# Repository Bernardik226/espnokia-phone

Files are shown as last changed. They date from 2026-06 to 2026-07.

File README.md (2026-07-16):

<p align="center">
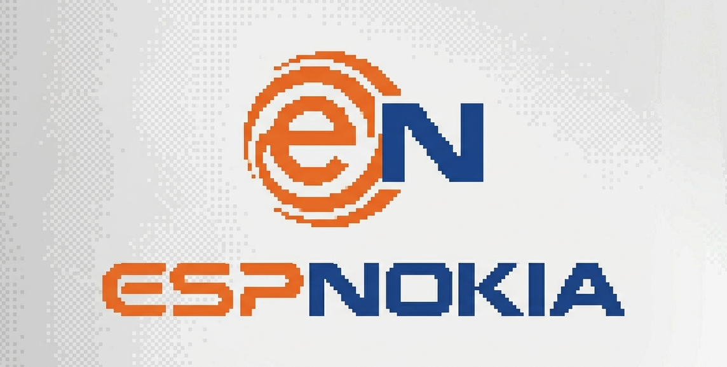
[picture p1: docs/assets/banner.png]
ESPNOKIA
  
</p>

<p align="center">
  
  
  
  
</p>

<p align="center">
  
  
  
  
</p>

<p align="center">
  🇬🇧 English&nbsp;&nbsp;·&nbsp;&nbsp;<a href="README.pt-br.md">🇧🇷 Português</a>&nbsp;&nbsp;·&nbsp;&nbsp;<a href="docs/INSTALL.md">🔧 Build yours</a>&nbsp;&nbsp;·&nbsp;&nbsp;<a href="docs/ARQUITETURA.md">🏛️ Architecture</a>&nbsp;&nbsp;·&nbsp;&nbsp;<a href="docs/MAKE_AN_APP.md">🧩 Make an app</a>
</p>

---

<p align="center"><b>A Nokia 3310 that talks to Claude — firmware, printed case, backend and PWA, all built by me.</b></p>

I built this handheld from scratch to fold everything I wanted to show into one project: **embedded firmware** on an ESP32, a **case I designed and printed**, an **AI-powered FastAPI backend** and a **configuration PWA**. It's my end-to-end portfolio — from the pixel on the 84×48 screen to the container on deploy. Year-2000 looks, 2026 features.

<p align="center">
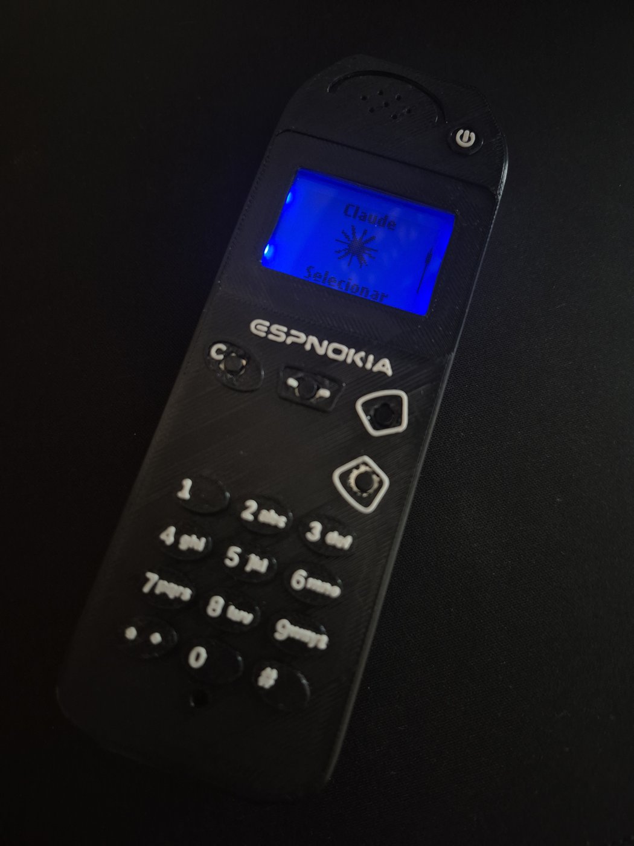
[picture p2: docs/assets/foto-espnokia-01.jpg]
assembled espnokia — the printed, powered device showing the Claude app on screen
  
</p>

<p align="center">
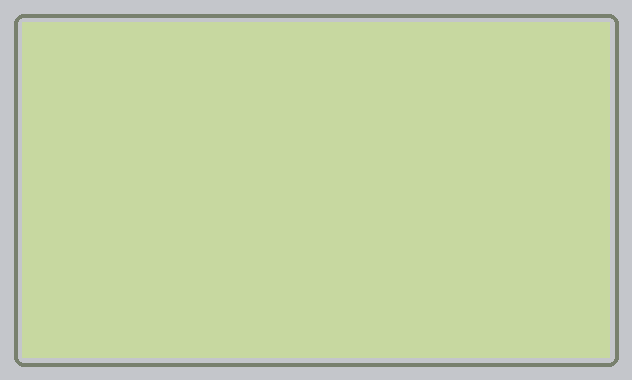
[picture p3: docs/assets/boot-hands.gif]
the recreated Nokia boot animation: two pixel hands meet and the logo lights up
  
</p>

---

## ✨ What it does

- 🐾 **Claw'd — talk to Claude.** Hold the button, speak, release: the mic captures, the server transcribes, **Claude answers**, and a pixel-art critter reads the reply on the little screen. Every exchange becomes a **log**, and a rolling **memory** lets the pet remember you across reboots.
- 🏆 **World Cup 2026, live.** Upcoming matches, Brazil's games, a live panel and group tables. Flag a match and the device **rings when it kicks off**; the score updates on its own and **"GOAL!" flashes on screen** the instant it changes.
- ⚽ **Club leagues.** Champions League, Libertadores and friends, with a standings table that **adapts to the competition** (numbered league table / navigable groups).
- ⏰ **3310-style daily life.** A clock with an **alarm that survives reboots** and a timer, ambient temperature from the DS3231, and **9 original Nokia ringtones** in RTTTL.
- 🐍 **Snake II.** The classic, with its own engine tested on the PC.
- 📶 **WiFi with no recompile.** The device becomes an access point with a captive portal and a freshly-drawn password — switch network and server URL with no cable and no reflash.
- 🌍 **9 languages** across the whole system; **99 native tests** of pure logic + **157 on the server**.

<table align="center">
<tr>
<td align="center" width="50%">
  push-to-talk with Claw'd: listening, thinking, answering<br>
  <b>🐾 Claw'd</b> — hold, speak, Claude answers
</td>
<td align="center" width="50%">
  navigating the World Cup app on the device<br>
  <b>🏆 WC 26</b> — live on an 84×48 screen
</td>
</tr>
</table>

<p align="center">
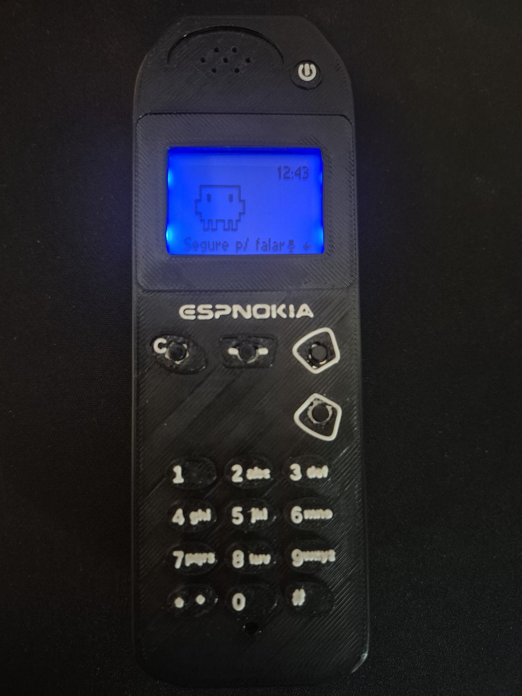
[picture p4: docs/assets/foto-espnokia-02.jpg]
espnokia in use — the clock and the Claw'd pet on the monochrome screen
  
</p>

**Configuration via the PWA.** An installable web panel (the "EspNokia Dash") **configures the device**: pair/discover by QR, see the **online status**, pick **Claude's personality**, the transcription engine, and drop in the **AI key** — with no config screen on the Nokia itself.

---

## 🔍 How it works

It's **three pieces** that talk over an authenticated API (`X-Device-Key`). The ESP32 is a plain chip, **no PSRAM** and with little RAM/flash — so it stores no history and transcribes nothing: it keeps only fixed buffers, a state machine, and **paginates** what it needs. All the durable state (the pet's memory, transcription, Claude calls) lives on the **server**, which **summarizes** old conversations so the context never grows without bound.

> **The core idea:** a *thin client* on the ESP32 (fixed, byte-capped buffers) + a *fat server* that holds and summarizes the history. That's how the firmware fits in **~⅓ of the flash and ¼ of the RAM** (flash 36.1% / RAM 25.6%).

```mermaid
flowchart LR
    D["📟 Firmware (ESP32)<br/>thin client"]
    S["🐍 Server (FastAPI · Docker)<br/>fat server"]
    P["📱 PWA<br/>configuration"]
    D -- "POST /claude/voz · PCM16<br/>GET /copa /futebol /claude/registro" --> S
    S -- "lean JSON · paginated text" --> D
    P -- "/admin/* · X-Device-Key" --> S
```

Architecture and technical decisions → **[docs/ARQUITETURA.md](docs/ARQUITETURA.md)** (in Portuguese for now)

---

## 🔌 Hardware

| | Component | Role |
|---|---|---|
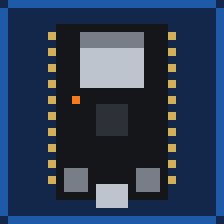
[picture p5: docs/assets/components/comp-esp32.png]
ESP32
|  | **ESP32 WROOM-32** DevKit, 30 pins | Brain: WiFi, 2 cores, the whole NokiaOS |
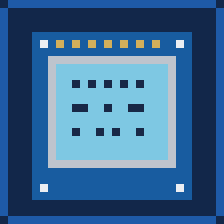
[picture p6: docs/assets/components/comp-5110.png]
Nokia 5110
|  | **Nokia 5110 display** (PCD8544) | 84×48 monochrome — the real Nokia panel, over SPI |
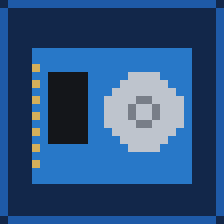
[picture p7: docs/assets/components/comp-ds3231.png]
DS3231
|  | **DS3231 RTC** | Battery-backed time + on-board thermometer, over I2C |
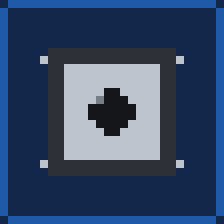
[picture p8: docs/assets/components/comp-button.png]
buttons
|  | **4 tactile buttons** | UP · DOWN · OK · C — full 3310-style navigation |
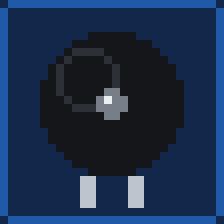
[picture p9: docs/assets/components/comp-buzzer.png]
buzzer
|  | **Passive buzzer** | RTTTL ringtones, beeps and the goal alert (volume via PWM) |
| 🎤 | **I2S mic INMP441** | Captures your voice for Claw'd |
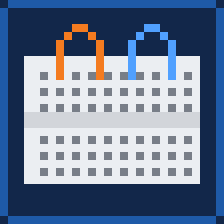
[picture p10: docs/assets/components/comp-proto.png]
breadboard
|  | **Breadboard + wires** | No-PCB, hand-wired build — full pinout in [`docs/INSTALL.md`](docs/INSTALL.md) |

> **No PCB, on purpose.** I chose to skip a dedicated board for simplicity and the low component count — I wired everything **by hand** (breadboard + soldering straight to the modules). The real challenge was soldering and securing all the wires; but closed inside the case, it all stays **discreet**. A PCB mainboard is planned for v2.

<table align="center">
<tr>
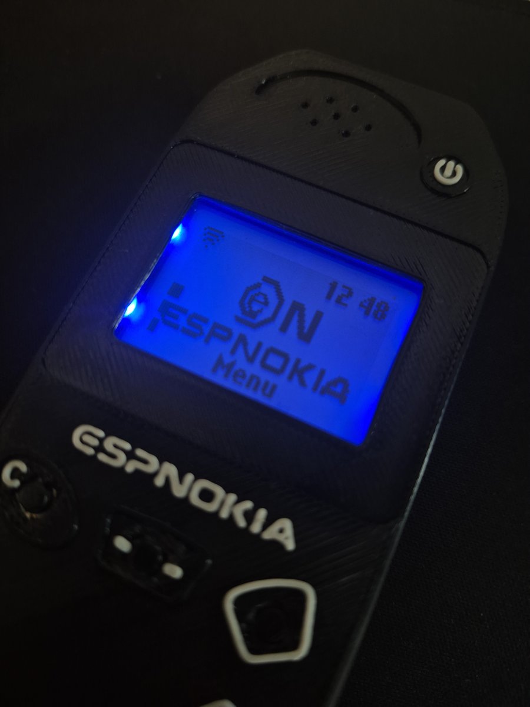
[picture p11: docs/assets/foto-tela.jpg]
close-up of the lit screen showing the eN emblem and the menu
<td align="center" width="33%"><br><sub><b>Lit screen</b> · eN + menu</sub></td>
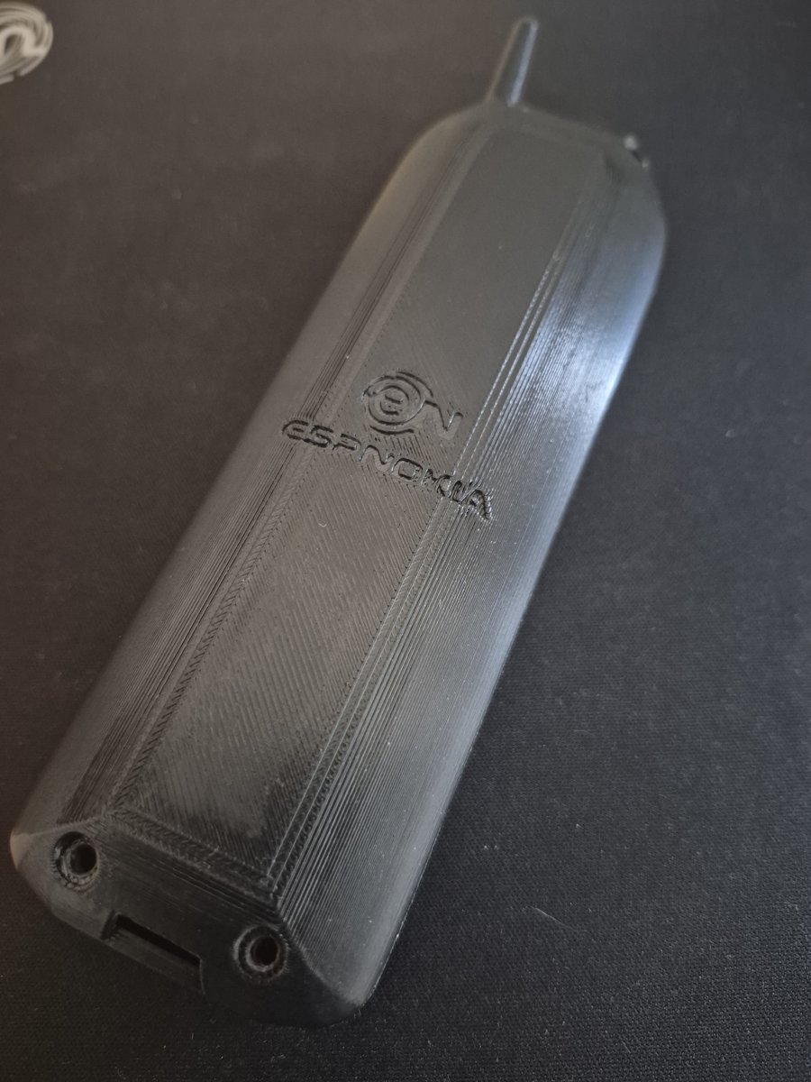
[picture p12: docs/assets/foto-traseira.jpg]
back cover with the eN emblem engraved into the dome
<td align="center" width="33%"><br><sub><b>Back</b> · logo engraved on the dome</sub></td>
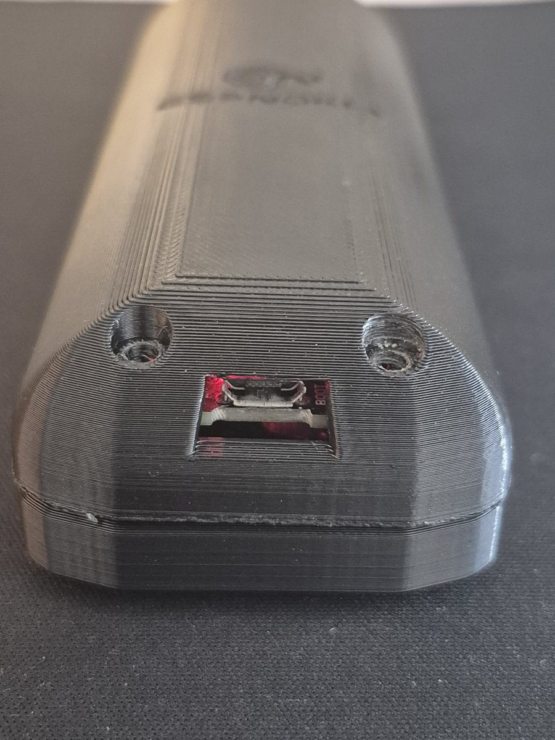
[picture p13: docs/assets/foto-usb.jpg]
USB port on the base — the ESP32's own micro-USB
<td align="center" width="33%"><br><sub><b>Base USB</b> · charge + flash via the ESP32</sub></td>
</tr>
</table>

**From file to part.** I designed the case in OpenSCAD/FreeCAD and exported the front as **multi-color** (black body + white silkscreen, two objects in one `.3mf`). The two slice-ready files (front + back) live in [`hardware/Case/print/`](hardware/Case/print) — just open and print.

<table align="center">
<tr>
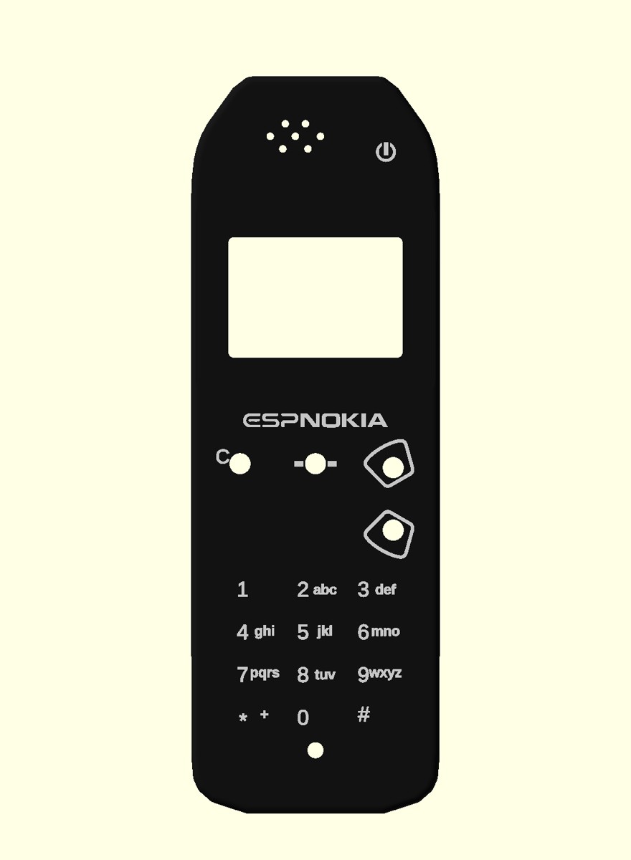
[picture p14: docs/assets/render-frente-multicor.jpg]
multi-color front render: black body and white silkscreen
<td align="center" width="50%"><br><sub><b>Multi-color front</b> · the final file (2 colors)</sub></td>
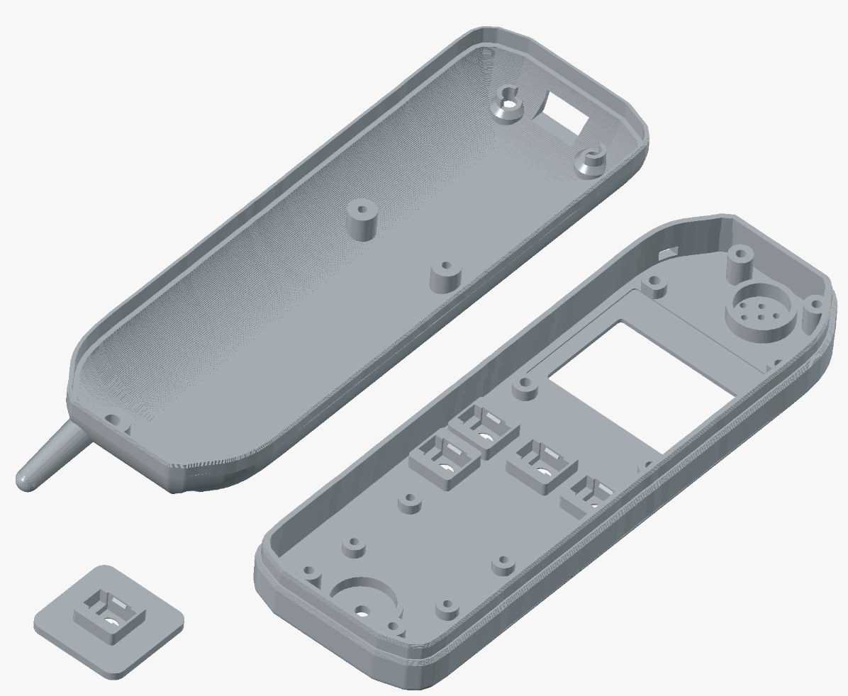
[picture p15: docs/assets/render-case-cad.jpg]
case opened in FreeCAD: front, back cover and a fit part
<td align="center" width="50%"><br><sub><b>In FreeCAD</b> · front + back + fits</sub></td>
</tr>
</table>

---

## 🚀 Run / build

```bash
# Firmware (PlatformIO) — from firmware/
cd firmware
pio run  -e esp32dev     # builds and flashes the ESP32
pio test -e native       # 99 pure-logic tests, run on the PC

# Server (FastAPI) — from server/
cd server
docker build -t espnokia .
docker run -p 8000:8000 --env-file .env espnokia   # ANTHROPIC_API_KEY is the only required one
```

**Deploy:** the plain `Dockerfile` runs on any container host — it's published on **Railway**. Then just open *Settings → Connections* on the device and point it at the server URL (no reflash). Full build guide in **[docs/INSTALL.md](docs/INSTALL.md)**.

---

## 🙏 Credits & attributions

This project stands on open work, with thanks:

- **Data** — [openfootball](https://github.com/openfootball/world-cup) (public-domain World Cup dataset) · **ESPN** (live scores and leagues via public endpoints; data © ESPN / The Walt Disney Company).
- **AI & voice** — [Anthropic Claude](https://www.anthropic.com/) (Claw'd's brain) · [faster-whisper](https://github.com/SYSTRAN/faster-whisper) (local STT) · [Groq](https://groq.com/) (cloud STT, optional).
- **Art & fonts** — [nokia-3310-fonts](https://git.janouch.name/p/nokia-3310-fonts) by **Premysl Janouch** · the Nokia 1100 boot and factory ringtones reproduced as an homage.
- **Libraries** — [U8g2](https://github.com/olikraus/u8g2) · [ArduinoJson](https://arduinojson.org/) · [QRCode](https://github.com/ricmoo/QRCode) · [FastAPI](https://fastapi.tiangolo.com/) · [Uvicorn](https://www.uvicorn.org/) · [httpx](https://www.python-httpx.org/) · [Anthropic SDK](https://github.com/anthropics/anthropic-sdk-python).

---

## ⚖️ Trademarks & authorship

**Nokia** and the Nokia phone designs are trademarks of **Nokia Corporation**. **Claude** and **Anthropic** are trademarks of **Anthropic, PBC**. The **FIFA World Cup** name and emblem are trademarks of **FIFA**. **Groq**, **ESPN** and other names belong to their respective owners. This is an independent, **non-commercial, fan & educational** project — a tribute — and is **not affiliated with, endorsed by, or sponsored by** any of them.

Original code, firmware, pixel art and assets © 2026 **Bernardo Melo**. Third-party components keep their own licenses.

<p align="center">
  Want one on your desk? → <a href="docs/INSTALL.md"><b>🔧 Build guide</b></a>
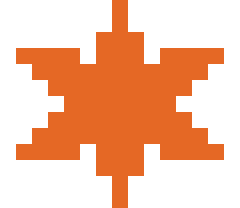
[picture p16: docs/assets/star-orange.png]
orange star
  &nbsp;·&nbsp;  built by <b>Bernardo Melo</b>
</p>

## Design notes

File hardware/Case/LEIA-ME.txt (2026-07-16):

=========================================================
espnokia — case (Nokia 5110) — imprimir & montar
=========================================================

2 pecas pra imprimir (print/) + 2 STL de conferencia de encaixe (sim/).

IMPRIMIR
--------
print/ (ja caem na orientacao certa no slicer — NAO virar):
- frente-multicor.3mf .. frente: corpo preto + serigrafia branca (logo,
                         teclado, simbolos). Sao 2 objetos/cores no mesmo
                         arquivo -> numa impressora de 1 bico, faca troca de
                         filamento (pausa na camada onde a serigrafia comeca).
                         Botoes de navegacao em relevo, switch direto, torres
                         do RTC atras do teclado.
- case-capa.3mf ........ tampa traseira; furo do USB com funil, luvas
                         meia-lua p/ os botoes do ESP, sem RTC.

Orientacao: a frente sai com o TECLADO PRA CIMA; a capa com o DOMO PRA CIMA
(boca pra baixo). Nao virar nenhuma das duas.

Perfil sugerido (ABS resistente):
- camada 0,16mm (primeira camada 0,20)
- 4 paredes; topo/fundo 5/4; infill 40% GIROIDE (nao use grid)
- suporte NORMAL (grade), "apenas na mesa", com interface — NAO use arvore
- brim 8-10mm
- ABS: bico 245-255 / mesa ~100, camara fechada, fan baixa
- no preview: nada de suporte sobre a face do teclado

sim/ (NAO imprimir — so p/ conferir encaixe no FreeCAD):
- sim-tela-modulo.stl .. modulo 5110 nas medidas reais
- sim-esp32-capa.stl ... ESP32 DevKit no lugar de montagem (confere USB,
                         botoes e pinos)

MONTAR
------
1) Switches tatil 6x6 por TRAS da frente, ate estalarem nos bercos. A ponta
   do atuador sai pelo furo -> o dedo clica direto nela.
2) ESP32 na TAMPA, de cabeca pra baixo: componentes/USB contra o fundo, pinos
   pra cima. Parafuse so os 2 furos de cima; os 2 de baixo recebem os
   parafusos da case ao fechar.
3) RTC DS3231 na FRENTE, deitado atras do teclado (socket da pilha pra cima).
4) Bateria (com modulo de carga) colada no fundo da tampa.
5) Feche: 4 parafusos pelas costas (os 2 de baixo atravessam os furos do ESP).

LIGACAO (carga + flash pela porta USB da base = micro-USB do proprio ESP32)
--------
  VIN/5V do ESP --> IN+ do TP4056
  TP4056 B+/B-  --> bateria LiPo
  TP4056 OUT+   --> diodo Schottky (SS14/1N5817) --> VIN do ESP
  TP4056 OUT-   --> GND comum
  Com USB: os 5V carregam a bateria (o Schottky bloqueia o retorno).
  Sem USB: bateria -> Schottky -> VIN -> regulador 3,3V da placa.
  (Carregue de preferencia com o aparelho desligado.)

LIGA/DESLIGA
------------
Mini chave deslizante na lateral direita (o relevo do power na frente e
decorativo). Ligacao: VOUT+ da bateria (apos o diodo) -> chave -> VIN.

PARAFUSOS
---------
- 2x M2,5 ~20mm .. fecham a case por baixo (atravessam o furo do ESP)
- 2x M2,5 6-8mm . ESP32 nos standoffs de cima
- 4x M2,5 4-5mm . RTC nas torres da frente
- 2x M2,5 ~16mm . case por cima
- 4x M3 curto ... tela nos bosses da frente

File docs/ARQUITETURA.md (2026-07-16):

# Arquitetura & decisões técnicas — espnokia-phone

Este documento explica **como o projeto está montado por dentro** e as decisões que tomei pra fazer um handheld estilo Nokia 3310 rodar um assistente de voz com o Claude — mantendo histórico de conversa — num **ESP32 comum, sem PSRAM**. Se você quer a visão de vitrine (o que o aparelho faz), volte pro [README](../README.pt-br.md); aqui é a parte de engenharia.

O fio condutor é um só: **cliente magro no firmware, server gordo no backend.** O chip guarda o mínimo e pagina o resto; o server segura o estado durável e resume o que fica grande demais.

---

## 1. As 3 partes + contrato de API

| Parte | Stack | Papel |
|---|---|---|
| **Firmware** | ESP32 (C++17 / Arduino / U8g2, PlatformIO) | Cliente magro: UI, captura de voz, paginação sob demanda |
| **Server** | FastAPI / Uvicorn (Docker) | Server gordo: transcrição, chamadas ao Claude, memória durável, mastiga fontes de dados |
| **PWA** | HTML/JS de página única (sem framework) | Configuração do aparelho: pareamento, status, chaves, persona |

O firmware **nunca** toca uma fonte externa direto — ele só fala com o *meu* server, que é a membrana entre um buffer de poucos KB e a internet aberta. Toda rota (menos o essencial de saúde/PWA) exige o header **`X-Device-Key`**.

### Autenticação — `X-Device-Key` (`server/app/auth.py`)

A dependency `make_auth` valida o header em 3 modos, pela env `DEVICE_KEYS`:

- **`""`** → auth desligada (dev local).
- **`"*"`** → modo **capability**: aceita qualquer chave com `len ≥ 16`. A própria chave forte (32 hex = 128 bits, gerada no device) *é* a credencial; não há lista de usuários no servidor, e os dados ficam **isolados por hash da chave**. É o modo do pareamento por QR — um aparelho se registra sem cadastro central.
- **`"a,b"`** → allowlist clássica de chaves.

O dashboard e o device usam **a mesma auth**: o painel web é literalmente o mesmo "device" logado com a chave.

### Rotas

**Device-facing** (chamadas pelo firmware ESP32):

| Método | Rota | O que faz |
|---|---|---|
| `GET` | `/health` | Ping de keep-alive do socket — **sem auth**. |
| `GET` | `/copa/proximos?n=8` · `/copa/brasil` · `/copa/live` · `/copa/grupos` | Placares/tabela da Copa 2026 (payload compactado, chaves de 1 letra pra caber no buffer do ESP32). |
| `GET` | `/futebol/ligas` · `/futebol/jogos?liga=` · `/futebol/live?liga=` · `/futebol/tabela?liga=` | Futebol de clubes (ligas, jogos, ao vivo, classificação). |
| `POST` | `/claude/voz?lang=pt&t=` | **Rota central da voz.** Corpo = PCM16 cru; dispara STT → Claude → resposta; se o histórico encheu, agenda o resumo em background. |
| `GET` | `/claude/registro?pag=0` | Histórico paginado (6 pares por página). |
| `GET` | `/claude/memoria` | Memória resumida (markdown) + contador de resumos. |
| `POST` | `/claude/memoria/limpar` | Apaga registro + memória ("esquecer tudo"). |

**PWA / admin-facing** (dashboard):

| Método | Rota | O que faz |
|---|---|---|
| `GET` | `/admin/status` | Versão, motor de STT, modelo, web search, se tem API key, total de conversas, nº de resumos, timestamp da memória. |
| `GET` | `/admin/config` | Config atual: `persona_id` + catálogo de personas, modelo, STT, limite de resposta, web search, e **flags booleanas** `tem_anthropic_key` / `tem_stt_key` — **nunca a chave crua**. |
| `POST` | `/admin/config` | Grava campos parciais; a chave de API só é sobrescrita se vier não-vazia (evita apagar sem querer); `persona_id` só é aceito se existir no catálogo. |
| `GET` | `/manifest.json` · `/sw.js` · `/` | Shell do PWA (sem auth). |

---

## 2. A restrição-chave e como resolvi

**O problema:** rodar o Claude *com memória de conversa* num ESP32 WROOM-32 — sem PSRAM, com RAM e flash apertadas (por isso `board=esp32dev` + partição `huge_app.csv`: abri mão de OTA/SPIFFS pra ter espaço de código). Um histórico de chat cresce sem limite; um buffer de resposta multibyte estoura fácil; e transcrição de áudio no chip é impensável.

**A solução:** dividir responsabilidades. O device fica *magro*; o server fica *gordo*.

### Lado device — só o que cabe em RAM fixa

- **Buffers fixos, dimensionados em bytes** (`firmware/lib/claudemodel/claudemodel.h`). Nada de alocação dinâmica:
  ```cpp
  struct RegPar {
    char q[164];   // MAX_Q_BYTES do server (160) + nul
    char r[284];   // MAX_R_BYTES do server (280) + nul
    char d[6];     // "dd/mm"
    char h[6];     // "hh:mm"
  };
  ```
  Os tamanhos **164 / 284 espelham literalmente** os tetos do server (`MAX_Q_BYTES` / `MAX_R_BYTES` + 1): o firmware não decide o teto sozinho, ele reflete o do servidor. `registro_parse(RegPar* itens, uint8_t max)` recebe do *caller* quantos pares cabem — quem manda na RAM é o app, não a lib.
- **Máquina de estados push-to-talk** (testável no PC, sem Arduino):
  ```
  E_PET → (OK aperta) → E_OUVINDO → (OK solta) → E_PENSANDO → (resposta|falha) → E_FALANDO → (volta) → E_PET
  ```
  Com timeouts de segurança: `kOuvindoMaxMs = 15 s` corta a gravação; `kFalandoMaxMs = 60 s` volta sozinho ao pet. O `E_PENSANDO` **não** tem timeout próprio de propósito — quem corta é o timeout do cliente HTTP (`kRespTimeoutMs = 20 s`).
- **Paginação, não replicação.** O histórico completo **não existe no device**: `GET /claude/registro?pag=N` devolve só uma página (6 pares), e o firmware guarda no máximo o array da página atual. Entre reboots o device persiste só **a chave e a URL do server** (em NVS) — nenhuma conversa fica na flash.
- **Consciência de heap explícita.** O upload de voz vai por **HTTP chunked**: o PCM16 é escrito direto no socket TLS conforme a captura, chunk a chunk, sem montar o corpo inteiro em RAM. O socket TLS é mantido "quente" e reusado entre chamadas, e `ESP.getFreeHeap()` é logado em cada tentativa de rede. (O TLS usa `setInsecure()` de propósito — "o segredo do device é a chave, não o canal"; o ESP32 não carrega um bundle de CAs atualizado.)

### Lado server — o estado durável e o resumo (`server/app/memoria.py`)

Esse arquivo é o coração da solução. Por device, guardo em disco (`DATA_DIR/claw/<id8>/`, onde `id8 = sha256(chave)[:8]` — a chave secreta nunca vira nome de pasta):

- **`registro.json`** — `{"pares": [...], "resumidos": int}`; cada par é `{ts, q, r}`. Escrita **atômica** (`tmp` + `os.replace`).
- **`memoria.md`** — texto livre em markdown, um resumo cumulativo em 1ª pessoa que o **próprio Claude** escreve. Legível de propósito.

Os limites que governam tudo:

```python
MAX_PARES = 30           # atingiu -> dispara resumo
VARRE     = 20           # pares mais antigos fundidos na memória e removidos
TETO      = 40           # rede de segurança: acima disso descarta o mais antigo
PARES_POR_PAG = 6        # paginação do GET /claude/registro
MAX_Q_BYTES = 160        # pergunta truncada (buffer do ESP32)
MAX_R_BYTES = 280        # resposta truncada (buffer do ESP32)
MAX_MEMORIA_CHARS = 1500 # teto do memoria.md
```

**O mecanismo de resumo (contexto limitado):**

1. Depois de cada `/claude/voz` bem-sucedido, `precisa_resumo()` checa se `len(pares) ≥ 30`. Se sim, agenda `resumir()` num **`BackgroundTasks`** — não bloqueia a resposta ao aparelho, e se falhar só loga.
2. `resumir()` pega os **20 pares mais antigos** + o `memoria.md` atual e pede pro Claude **reescrever a memória inteira** em 1ª pessoa, no idioma do usuário, em até **1500 caracteres**. Ou seja: cada resumo **funde** o velho com o novo e é resumido de novo — não é um log incremental, o tamanho fica sempre controlado.
3. O resultado é truncado e salvo atomicamente; os 20 pares resumidos são removidos do `registro.json` — mas o registro é **recarregado do disco antes de filtrar**, pra não perder um par que chegou enquanto o resumo (em background) pensava.
4. **Rede de segurança:** se o resumo nunca rodar (sem API key, falha contínua), `grava_par` corta o array pros últimos **40 pares** a cada gravação — um cap duro que impede o `registro.json` de crescer sem limite, ao custo de descartar silenciosamente os mais antigos ainda não resumidos.

O efeito é o que importa: **o contexto que mando pro Claude a cada fala nunca é o histórico completo.** É `memoria.md` (≤ 1500 chars) + só os **últimos 6 pares** crus + a fala atual. O histórico completo em disco existe só pra exibição paginada no aparelho/dashboard — jamais é reenviado inteiro ao modelo.

### `corta_utf8` — a ponte de segurança de bytes entre Python e C

O truncamento é feito **em bytes, não em caracteres Python**, porque o firmware aloca `char q[164]` / `char r[284]` fixos. Cortar por caractere estouraria o buffer C num texto multibyte (acentos, emoji):

```python
def corta_utf8(s: str, max_bytes: int) -> str:
    b = s.encode("utf-8")
    if len(b) <= max_bytes:
        return s
    corte = b[:max_bytes - 3]          # reserva 3 bytes pro "…"
    while corte:
        try:
            return corte.decode("utf-8") + "…"
        except UnicodeDecodeError:
            corte = corte[:-1]         # descarta byte de continuação partido
    return "…"
```

Uso o mesmo `corta_utf8` no corte ao vivo da resposta e na paginação do histórico — assim a fala "ao vivo" e o registro mostram **exatamente o mesmo texto**, e o firmware nunca recebe mais bytes do que o buffer aguenta.

### Footprint

Com o NokiaOS inteiro, os apps, WiFi/TLS e o pipeline de voz, o firmware ocupa **flash 36.1% / RAM 25.6%** — cerca de um terço da flash e um quarto da RAM. Sobra folga de propósito: cada nova tela é uma struct de callbacks, não uma reforma de memória.

<p align="center">
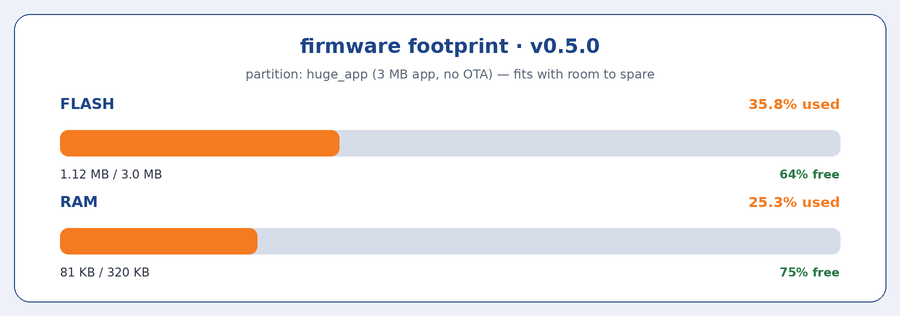
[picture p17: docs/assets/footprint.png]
footprint do firmware na partição huge_app: flash ~36% usada, RAM ~26% usada
  
</p>

---

## 3. Transcrição (STT)

A transcrição é **plugável** via `cfg["stt"]` (default `"local"`), trocável pelo dashboard sem reflash:

- **`local`** (padrão) — **faster-whisper `small`, quantização int8, na CPU**. É **lazy-load**: o modelo só carrega na primeira fala, pra não atrasar o boot; com `STT_PRELOAD=1` eu aqueço no boot quando quero latência baixa já na primeira interação. Roda sem depender de rede nem de chave externa.
- **`groq`** (opcional) — `POST` pra `api.groq.com/.../audio/transcriptions`, modelo **`whisper-large-v3-turbo`** (mais rápido/melhor, mas precisa de chave e rede).

### O fluxo de uma fala (`server/app/claude_voz.py`)

```
PCM16 16 kHz cru no corpo (MAX_CORPO = 500 KB ≈ 15,6 s)
   → transcrever()                       # STT local ou Groq
   → _chat_anthropic()                   # Claude Messages API
        · modelo vindo do cfg (classe Haiku, por custo/latência)
        · max_tokens = 300               # cabe na tela e segura o custo
        · web search server-side, max_uses = 1   # ≤ 1 busca por fala
   → JSON  { resposta, humor, ... }       # texto já cortado no orçamento de bytes
```

O ponto que amarra tudo à seção anterior: **a memória resumida (`memoria.md`) entra no `system` prompt** do Claude a cada fala. É isso que dá continuidade — o pet lembra de você **mesmo depois de reiniciar o server**, sem nunca carregar o histórico cru inteiro no contexto. A resposta já sai truncada pelo mesmo teto de bytes que o ESP32 pagina, então o que o Claude gera, o que a tela mostra e o que o histórico guarda são o mesmo texto.

---

## 4. O que a PWA configura

O PWA (`server/app/static/dashboard.html`) é um SPA de página única, sem framework, com i18n embutido (9 idiomas, troca em runtime persistida em `localStorage`). Ele não é firmware — é o **painel de configuração do aparelho**, instalável no celular. Descrevo aqui por **função** (a aparência será reformulada numa próxima rodada):

- **Pareamento por QR / descoberta.** O aparelho sorteia a própria chave no primeiro boot (RNG de hardware → NVS) e mostra um QR com o link `.../#k=<chave>`. Ao abrir, o JS lê a chave do fragmento, entra **já logado** e limpa a URL (`history.replaceState`) — a chave não fica visível na barra de endereço.
- **Login por chave.** Campo de chave testado contra `GET /admin/status`; 401 mostra "chave recusada", chave válida persiste em `localStorage`.
- **Status online.** Espelho read-only de `/admin/status`: versão, nº de conversas, nº de resumos, motor de STT, modelo, se a web search está ligada, se a chave Anthropic está configurada, quando a memória foi atualizada.
- **Configuração do Claw'd.** Escolher a **personalidade/persona** (catálogo em `config.PERSONAS`, ex.: Fofo, Sarcástico, Poeta, Sábio…), o **motor de STT** (local/Groq), o **modelo** do Claude, o **limite de resposta**, ligar/desligar **busca web**, e colar a **chave de API Anthropic** (campo senha — vazio = manter a atual). Grava via `POST /admin/config`.
- **Memória & conversas.** Ler o `memoria.md` cru, apagar tudo ("esquecer tudo" → `/claude/memoria/limpar`), e navegar as conversas paginadas (`/claude/registro`).

Não há gestão multi-device nem contas: **1 chave = 1 device = 1 sessão de configuração**.

---

## 5. Infra & organização

- **Dockerizado.** `server/Dockerfile` parte de `python:3.12-slim`, copia `requirements.txt` primeiro (cache de layer), expõe a 8000 e roda `uvicorn app.main:app`. Imagem simples, deploy único.
- **Pastas isoladas**, cada uma com seu próprio ciclo de build/test — sem tooling de monorepo compartilhado:
  ```
  firmware/   NokiaOS em C++/Arduino (PlatformIO: esp32dev + native)
    lib/      lógica pura testável: shell, btnlogic, rtttl, i18n, copamodel, claudemodel, snakegame...
    src/      drivers, apps, som, rede (wifi/http/ntp/provisionamento), conn
  server/     companion FastAPI: /copa /futebol /claude /admin + o dashboard PWA
  hardware/   case 3D / STL / configs de impressão
  docs/       instalação, arquitetura, assets
  tools/      utilitários de pixel art (grade → XBM)
  ```
- **Testes nativos.** `firmware/test/` roda no PC via PlatformIO Unity (ambiente `[env:native]`, sem placa): **99 casos** cobrindo shell, botões, RTTTL, formatação de hora, parse da Copa/futebol, o modelo do Claw'd, i18n e o Snake. `server/tests/` são **157 testes pytest** (fontes mockadas, auth, cache, personas, memória, endpoints). A separação `drivers/` (hardware) · `lib/` (lógica pura portável) · `apps/` (UI) é justamente o que permite testar no PC o que roda no ESP32.
- **Deploy — Railway.** O contrato de deploy é o `Dockerfile` plano (sem `railway.json`/`Procfile` versionados), compatível com Railway ou qualquer host de container. Envs relevantes: `DEVICE_KEYS` (allowlist / vazio / `*` capability), `ANTHROPIC_API_KEY` e `GROQ_API_KEY` (seed inicial, depois editáveis só pelo dashboard), `DATA_DIR`, `STT_BACKEND`, `STT_PRELOAD`, `LIVE_SOURCE_URL` (fonte reserva de placar ao vivo).

---

*Voltar pra vitrine → [README](../README.pt-br.md) · Montar o seu → [docs/INSTALL.pt-br.md](INSTALL.pt-br.md)*

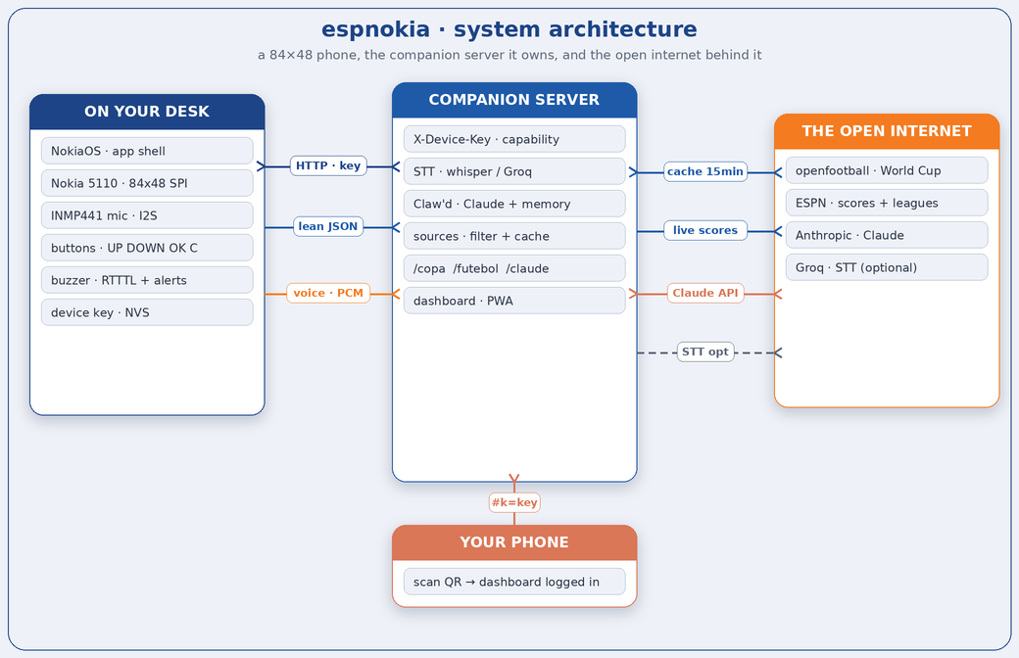
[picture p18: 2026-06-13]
docs/assets/architecture.png

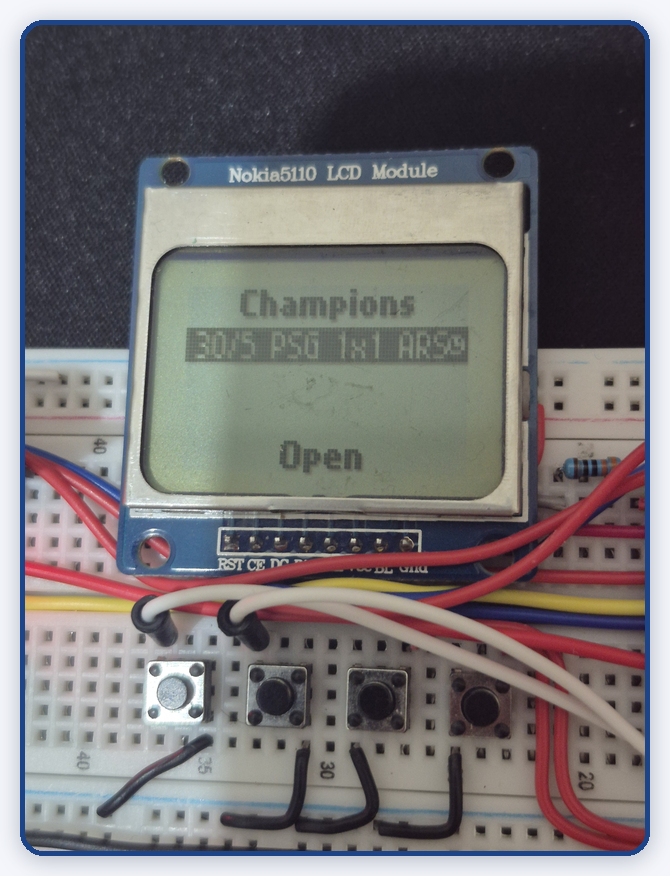
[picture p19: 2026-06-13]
docs/assets/photos/football-champions.png

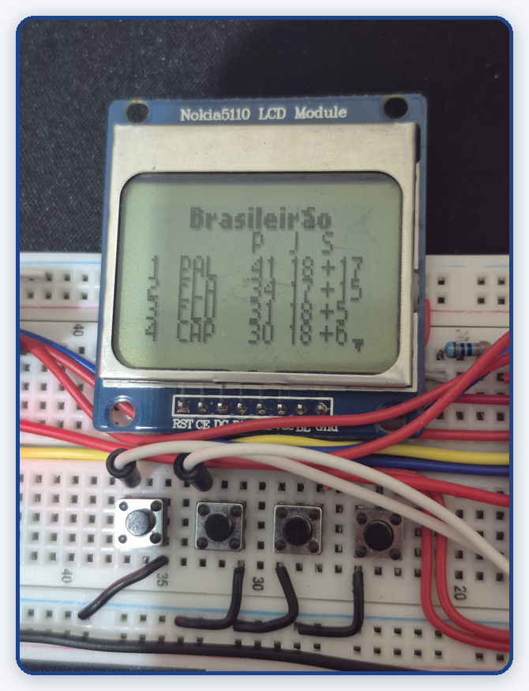
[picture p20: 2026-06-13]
docs/assets/photos/football-table.png

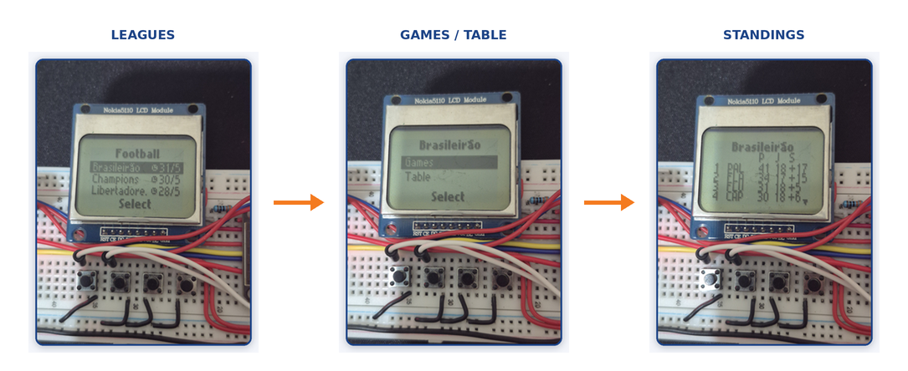
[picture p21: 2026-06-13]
docs/assets/flow-football.png

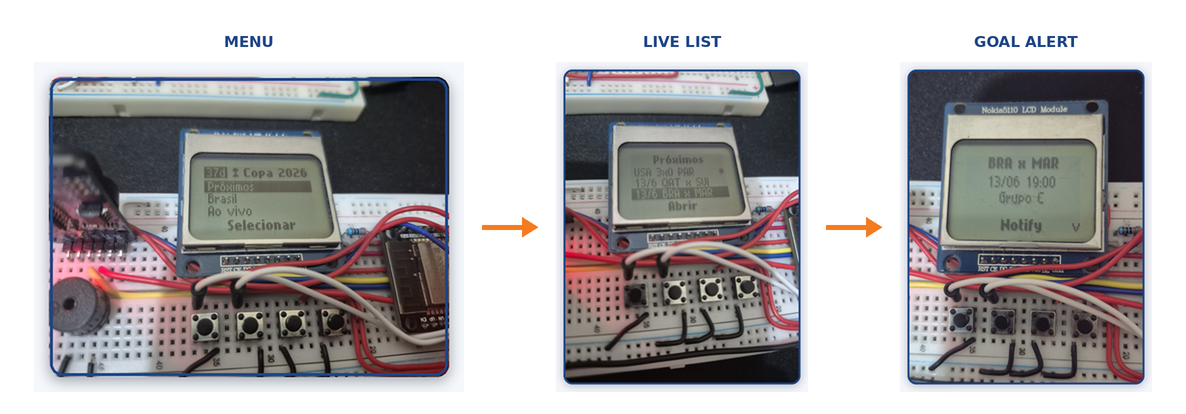
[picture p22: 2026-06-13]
docs/assets/flow-copa.png

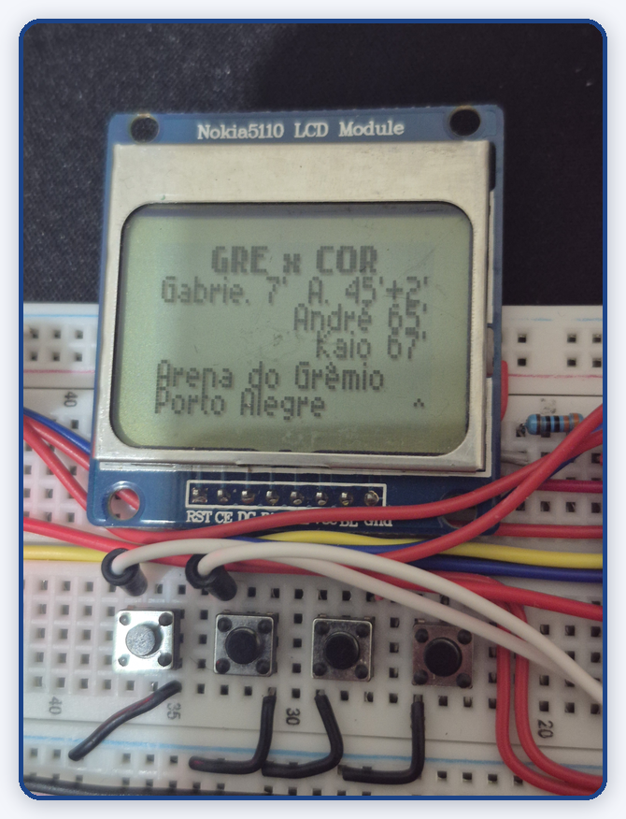
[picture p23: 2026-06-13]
docs/assets/photos/football-game.png

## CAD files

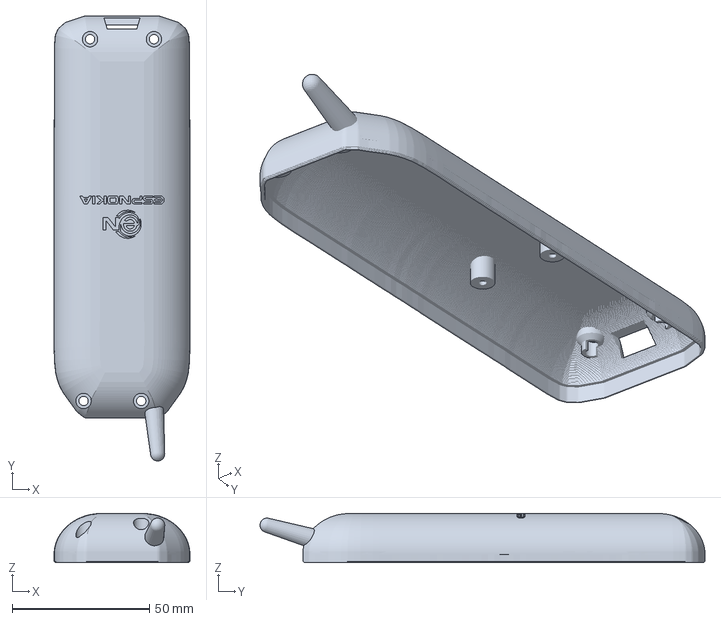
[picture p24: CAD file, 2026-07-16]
hardware/Case/print/case-capa.3mf
49.5 x 162.2 x 18.0 mm

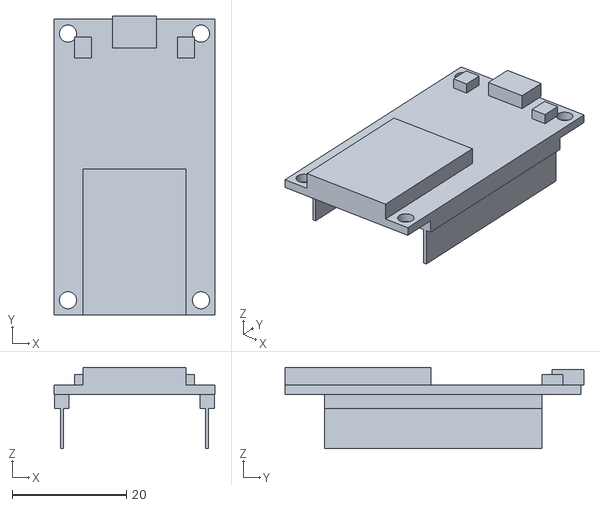
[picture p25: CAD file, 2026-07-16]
hardware/Case/sim/sim-esp32-capa.stl
28.2 x 52.3 x 14.2

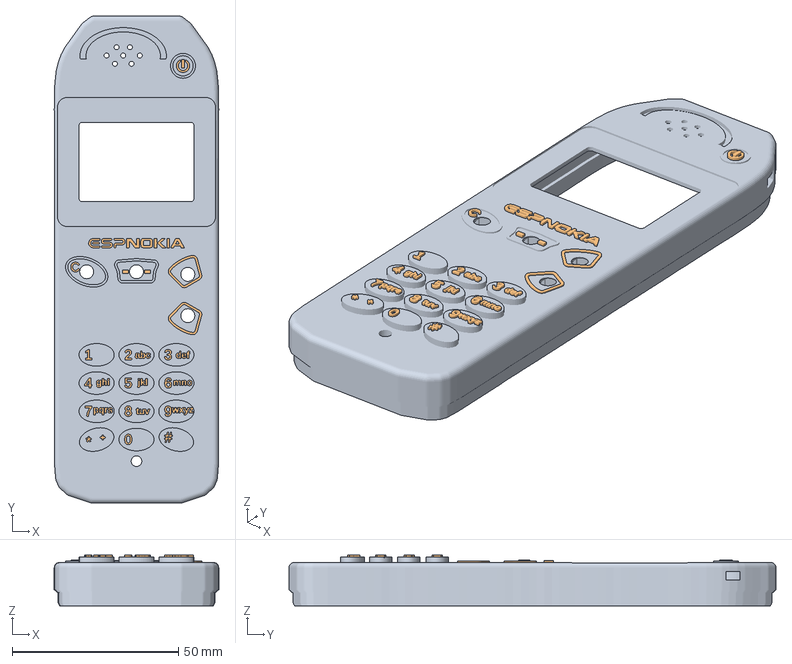
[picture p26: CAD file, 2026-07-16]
hardware/Case/print/frente-multicor.3mf
49.5 x 146.6 x 15.2 mm
corpo_cor
marcas_branco

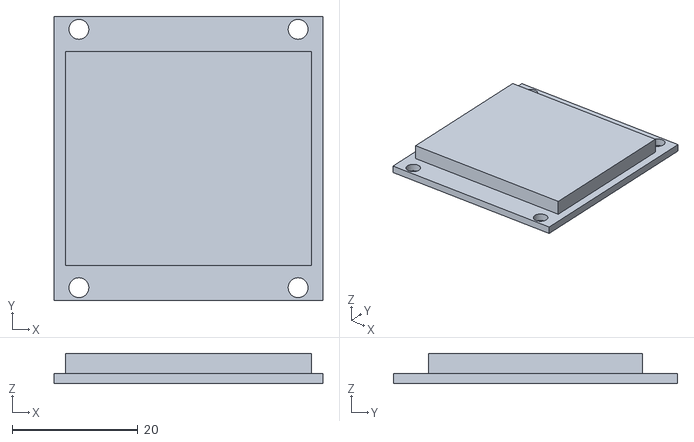
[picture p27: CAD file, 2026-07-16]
hardware/Case/sim/sim-tela-modulo.stl
42.7 x 45.1 x 4.80

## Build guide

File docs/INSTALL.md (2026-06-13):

<h3 align="center">
  <a href="../README.md">📟 Meet the project</a>&nbsp;&nbsp;·&nbsp;&nbsp;🔧 Build your own
</h3>

<p align="center">
  🇬🇧 English&nbsp;&nbsp;·&nbsp;&nbsp;<a href="INSTALL.pt-br.md">🇧🇷 Português</a>
</p>

# Build &amp; install

From zero to a phone that's powered on, following the World Cup and talking to
Claude: **build the hardware → run the server → flash the firmware → join WiFi →
pair Claw'd**. In that order.

---
## 🧰 Bill of materials

| Qty | Item | Notes |
|---|---|---|
| 1 | ESP32 WROOM-32 DevKit (30 pins) | Any DevKit with a USB-serial bridge (CP2102/CH340) works |
| 1 | Nokia 5110 display (PCD8544) | Module with backlight, 8 pins |
| 1 | DS3231 RTC (ZS-042 module or similar) | Optional, but without it there's no alarm and no offline time |
| 1 | CR2032 battery | Lets the DS3231 keep time while powered off |
| 4 | Tactile push buttons | UP, DOWN, OK and C |
| 1 | **Passive** buzzer | Passive only — an active one won't play melodies |
| 1 | INMP441 I2S microphone | For Claw'd (push-to-talk to Claude) — optional if you skip voice |
| 1 | Breadboard (830 pts) + jumpers | Solderless build |

---
## 🔌 Pinout

The source of truth is [`firmware/include/pins.h`](../firmware/include/pins.h):

| Module | Signal | GPIO |
|---|---|---|
| Nokia 5110 | CLK | 18 |
| | DIN | 23 |
| | DC | 17 |
| | CE | 5 |
| | RST | 16 |
| | BL (backlight) | 4 |
| Buttons | UP | 13 |
| | DOWN | 14 |
| | OK | 27 |
| | C | 26 |
| Buzzer | + | 25 |
| DS3231 | SDA | 21 |
| | SCL | 22 |
| INMP441 mic | SCK | 33 |
| | WS | 32 |
| | SD | 35 |

- Display and DS3231 on **3V3** (the 5110 does not tolerate 5 V).
- Buttons between the GPIO and **GND** — the firmware uses internal pull-ups.
- Passive buzzer: positive on GPIO 25, negative on GND.
- INMP441 on **3V3**; tie its `L/R` pin to GND (left channel).

<p align="center">
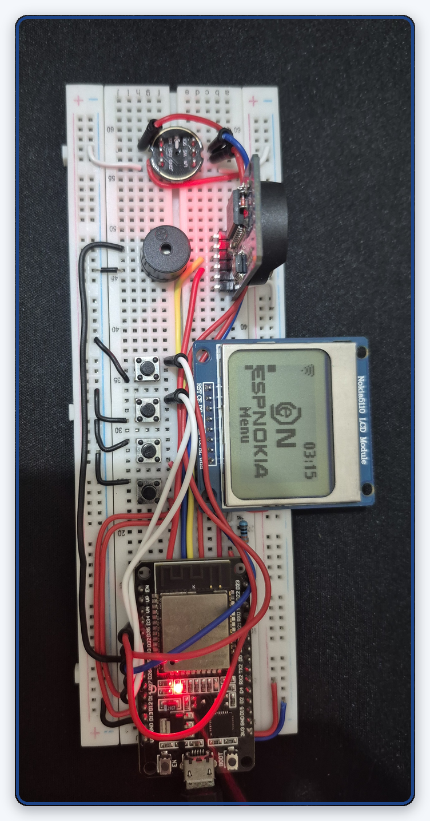
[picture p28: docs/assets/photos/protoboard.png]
the breadboard build with all components wired up
  
</p>

<sub>The full solderless build — every module on the breadboard.</sub>

---
## 🐍 Companion server

The server feeds the World Cup, the leagues and Claw'd. Run it on your machine,
a box at home, or any host that runs Python or a container — the firmware only
needs to reach the URL. **Bring your own keys: nothing is hosted for you.**

### Run it locally

```bash
cd server
python3 -m venv .venv && source .venv/bin/activate
pip install -r requirements.txt

cp .env.example .env        # edit it (see the table below)
export $(grep -v '^#' .env | xargs)
uvicorn app.main:app --host 0.0.0.0 --port 8000
```

### Run it with Docker

```bash
cd server
docker build -t espnokia-server .
docker run -p 8000:8000 \
  -e DEVICE_KEYS="*" \
  -e ANTHROPIC_API_KEY="sk-ant-..." \
  espnokia-server
```

### Environment variables

| Variable | What it does |
|---|---|
| `DEVICE_KEYS` | Keys accepted in the `X-Device-Key` header. Use `*` for **capability mode** (any strong key is accepted, data isolated per key) — the easy path when the device rolls its own key. A CSV of fixed keys also works. **Empty = auth off** (local dev only) |
| `ANTHROPIC_API_KEY` | Your Claude key — required for Claw'd. The persistent way to set it (a key typed in the dashboard only lasts while the server runs) |
| `GROQ_API_KEY` | Optional. Cloud speech-to-text; without it, STT runs locally with faster-whisper |
| `LIVE_SOURCE_URL` | Optional live-score source. Empty = off; the app still works from the table |
| `STT_PRELOAD` | Optional. `1` warms up the local whisper model at boot instead of on the first words |

### Smoke-check it

```bash
curl http://localhost:8000/health
# {"status":"ok"}

curl -H "X-Device-Key: any-strong-key-16+chars" "http://localhost:8000/copa/proximos?n=3"
# {"jogos":[...], "atualizado_s": 0}
```

With no key (or a weak/unknown one) the protected routes answer **401** — that's
the "API with a key" half of the project working.

### Server tests

```bash
pip install -r requirements-dev.txt
python -m pytest tests/        # 157 tests
```

---
## 📟 Firmware

Prerequisite: [PlatformIO](https://platformio.org/install/cli) (CLI or the
VS Code extension).

### 1. Configure the device

```bash
cd firmware
cp include/espnokia_config.example.h include/espnokia_config.h
```

`espnokia_config.h` is **gitignored on purpose** — secrets never reach the repo.
In v0.5.0 most of it is optional: the device **rolls its own device key** at
first boot and the **server URL is set from the phone** (no recompile). The
file only seeds the defaults:

```c
#define SERVER_URL  "http://192.168.0.10:8000"   // default URL; editable later on the device
#define DEVICE_KEY  ""                            // leave empty to let the device generate one
```

WiFi is **not** here — it's configured from your phone
([provisioning](#-joining-wifi)).

### 2. Test without a board

```bash
pio test -e native      # 82 tests running straight on the PC
```

### 3. Flash

```bash
pio run -e esp32dev -t upload
pio device monitor      # 115200 baud, to watch the boot
```

---
## 📶 Joining WiFi

On first power-up (or after **Settings → Connections → WiFi/Server → switch
network**) the device enters **config mode**:

1. The screen shows the network name (`espnokia-XXXX`) and an **8-digit numeric
   password** — drawn fresh each time you enter config mode, it only exists there.
2. Connect your phone to that network. The captive portal opens the page by
   itself (if it doesn't, go to `http://192.168.4.1`).
3. Tap your network in the list (padlock = protected; the bars show signal
   strength). **Hidden network?** Type its name in the manual field. Then enter
   the password and **SAVE** — the rescan button refreshes the list on the spot.
   The **server URL** field is on this same page.
4. The device reboots and connects. From here on, you just use it.

<p align="center">
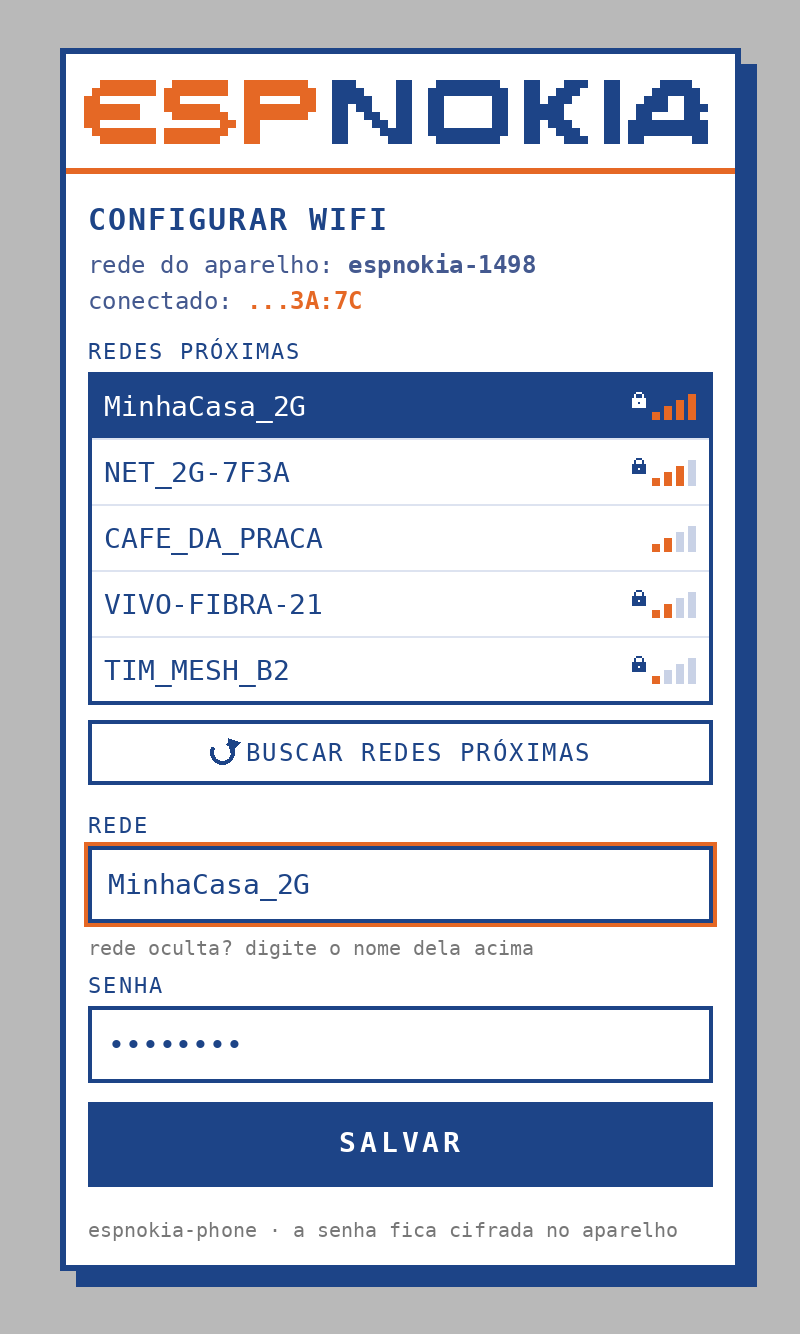
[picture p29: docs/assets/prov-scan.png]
config page with the network scan
  
  &nbsp;&nbsp;
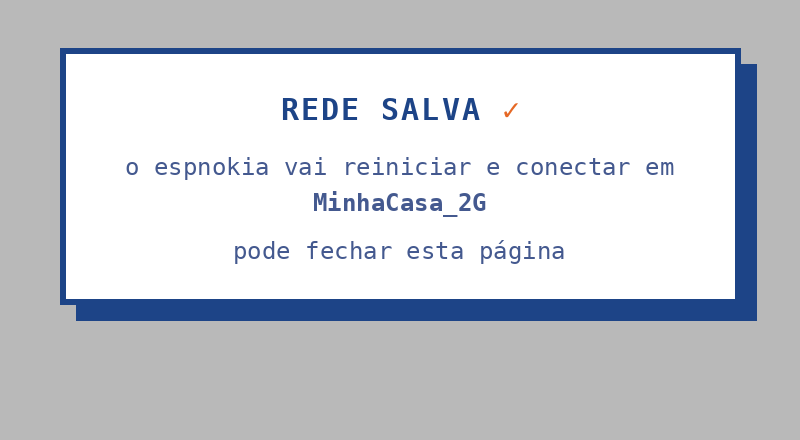
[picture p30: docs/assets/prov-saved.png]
network-saved confirmation
  
</p>

Your WiFi password is **encrypted in NVS** with a key derived from the chip's
own eFuse MAC. To wipe it: **Settings → Connections → WiFi/Server → forget**.

---
## 🐾 Pairing Claw'd &amp; the dashboard

Once the device is online and the server has an `ANTHROPIC_API_KEY`:

1. On the phone, go to **Settings → Connections → Device QR**. The screen shows
   a QR code built from your server URL and the device's own key.
2. Scan it with your phone's camera — the **dashboard opens already logged in**
   (the key rides in the URL fragment). Install it as a PWA if you like
   ("EspNokia Dash").
3. From the dashboard, set the **persona**, the **STT engine**, the **reply
   length**, read the pet's **memory** / recent **conversations**, or drop in
   your keys.
4. Open **Claw'd** on the phone, **hold the button and speak**, let go — the pet
   listens, thinks (the ✶ pulses) and reads Claude's reply back, page by page.

---
## 🚑 Common problems

| Symptom | Likely cause / fix |
|---|---|
| `pio run -t upload` can't find the port | Linux: join the `dialout` group (`sudo usermod -aG dialout $USER`, re-login). Check your board's USB-serial driver (CP2102/CH340) |
| Display lights up but shows nothing | Contrast/wiring: check CLK/DIN/DC/CE/RST against the [pinout](#-pinout); the 5110 is sensitive to a loose jumper |
| An app says "Connect WiFi" | The device has no network yet — run [provisioning](#-joining-wifi) |
| An app shows "NO RESPONSE" | The firmware didn't get a 200 from the server: check the server URL (right IP? right port? no trailing slash?), that the server is up (`curl .../health`), and that the device key is accepted (weak/unknown key = 401) |
| Claw'd never answers | The server has no `ANTHROPIC_API_KEY`, or the mic isn't wired (SCK 33 / WS 32 / SD 35, `L/R` to GND) |
| Clock has no time / no alarm | DS3231 missing or SDA/SCL swapped; without the RTC the clock runs but the alarm won't |
| Tones silent or one long tone | Active buzzer instead of passive, or reversed polarity |

---

<p align="center">
  Built it? → <a href="../README.md"><b>📟 Back to the project tour</b></a>
</p>

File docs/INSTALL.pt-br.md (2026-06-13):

<h3 align="center">
  <a href="../README.pt-br.md">📟 Conhecer o projeto</a>&nbsp;&nbsp;·&nbsp;&nbsp;🔧 Montar o seu
</h3>

<p align="center">
  <a href="INSTALL.md">🇬🇧 English</a>&nbsp;&nbsp;·&nbsp;&nbsp;🇧🇷 Português
</p>

# Montagem e instalação

Do zero até o aparelho ligado, acompanhando a Copa e conversando com o Claude:
**montar o hardware → subir o server → gravar o firmware → conectar no WiFi →
parear o Claw'd**. Nessa ordem.

---
## 🧰 Lista de materiais

| Qtde | Item | Observação |
|---|---|---|
| 1 | ESP32 WROOM-32 DevKit (30 pinos) | Qualquer DevKit com USB-serial (CP2102/CH340) serve |
| 1 | Display Nokia 5110 (PCD8544) | Módulo com backlight, 8 pinos |
| 1 | RTC DS3231 (módulo ZS-042 ou similar) | Opcional, mas sem ele não há alarme nem hora offline |
| 1 | Bateria CR2032 | Para o DS3231 segurar a hora desligado |
| 4 | Botão tátil (push button) | UP, DOWN, OK e C |
| 1 | Buzzer **passivo** | Passivo mesmo — o ativo não toca melodia |
| 1 | Microfone I2S INMP441 | Para o Claw'd (push-to-talk com o Claude) — opcional se dispensar a voz |
| 1 | Protoboard 830 pontos + jumpers | Montagem sem solda |

---
## 🔌 Pinagem

A fonte da verdade é [`firmware/include/pins.h`](../firmware/include/pins.h):

| Módulo | Sinal | GPIO |
|---|---|---|
| Nokia 5110 | CLK | 18 |
| | DIN | 23 |
| | DC | 17 |
| | CE | 5 |
| | RST | 16 |
| | BL (backlight) | 4 |
| Botões | UP | 13 |
| | DOWN | 14 |
| | OK | 27 |
| | C | 26 |
| Buzzer | + | 25 |
| DS3231 | SDA | 21 |
| | SCL | 22 |
| Mic INMP441 | SCK | 33 |
| | WS | 32 |
| | SD | 35 |

- Display e DS3231 em **3V3** (o 5110 não tolera 5 V).
- Botões entre o GPIO e o **GND** — o firmware usa pull-up interno.
- Buzzer passivo: positivo no GPIO 25, negativo no GND.
- INMP441 em **3V3**; ligue o pino `L/R` no GND (canal esquerdo).

<p align="center">
  a montagem na protoboard com todos os componentes
</p>

<sub>A montagem sem solda completa — cada módulo na protoboard.</sub>

---
## 🐍 Server companion

O server alimenta a Copa, as ligas e o Claw'd. Rode na sua máquina, num servidor
da sua casa ou em qualquer host que rode Python ou um container — o firmware só
precisa alcançar a URL. **Traga suas próprias chaves: nada é hospedado pra você.**

### Rodando local

```bash
cd server
python3 -m venv .venv && source .venv/bin/activate
pip install -r requirements.txt

cp .env.example .env        # edite (veja a tabela abaixo)
export $(grep -v '^#' .env | xargs)
uvicorn app.main:app --host 0.0.0.0 --port 8000
```

### Rodando com Docker

```bash
cd server
docker build -t espnokia-server .
docker run -p 8000:8000 \
  -e DEVICE_KEYS="*" \
  -e ANTHROPIC_API_KEY="sk-ant-..." \
  espnokia-server
```

### Variáveis de ambiente

| Variável | O que faz |
|---|---|
| `DEVICE_KEYS` | Chaves aceitas no header `X-Device-Key`. Use `*` pro **modo capability** (qualquer chave forte é aceita, dados isolados por chave) — o caminho fácil quando o aparelho sorteia a própria chave. Um CSV de chaves fixas também vale. **Vazio = auth desligada** (só em dev local) |
| `ANTHROPIC_API_KEY` | Sua chave do Claude — necessária pro Claw'd. É a forma persistente de definir (chave digitada no dashboard só vale enquanto o server roda) |
| `GROQ_API_KEY` | Opcional. Speech-to-text na nuvem; sem ela, o STT roda local com faster-whisper |
| `LIVE_SOURCE_URL` | Fonte opcional de placar ao vivo. Vazio = desligada; o app continua funcionando com a tabela |
| `STT_PRELOAD` | Opcional. `1` aquece o whisper local no boot em vez de na primeira fala |

### Conferindo

```bash
curl http://localhost:8000/health
# {"status":"ok"}

curl -H "X-Device-Key: uma-chave-forte-16+caracteres" "http://localhost:8000/copa/proximos?n=3"
# {"jogos":[...], "atualizado_s": 0}
```

Sem a chave (ou com uma fraca/desconhecida), as rotas protegidas respondem
**401** — é a parte "API com chave" do projeto funcionando.

### Testes do server

```bash
pip install -r requirements-dev.txt
python -m pytest tests/        # 157 testes
```

---
## 📟 Firmware

Pré-requisito: [PlatformIO](https://platformio.org/install/cli) (CLI ou
extensão do VS Code).

### 1. Configure o aparelho

```bash
cd firmware
cp include/espnokia_config.example.h include/espnokia_config.h
```

O `espnokia_config.h` é **gitignored de propósito** — segredo nunca vai pro
repositório. Na v0.5.0 quase tudo é opcional: o aparelho **sorteia a própria
chave de device** no primeiro boot e a **URL do server é definida pelo celular**
(sem recompilar). O arquivo só semeia os padrões:

```c
#define SERVER_URL  "http://192.168.0.10:8000"   // URL padrão; editável depois no aparelho
#define DEVICE_KEY  ""                            // vazio = o aparelho gera a própria chave
```

O WiFi **não** fica aqui — ele é configurado pelo celular
([provisionamento](#-conectando-no-wifi)).

### 2. Teste sem placa

```bash
pio test -e native      # 82 testes rodando direto no PC
```

### 3. Grave

```bash
pio run -e esp32dev -t upload
pio device monitor      # 115200 baud, pra acompanhar o boot
```

---
## 📶 Conectando no WiFi

Na primeira ligada (ou depois de **Config → Conexões → WiFi/Servidor → trocar de
rede**), o aparelho entra em **modo config**:

1. A telinha mostra o nome da rede (`espnokia-XXXX`) e uma **senha numérica de 8
   dígitos** — sorteada a cada entrada no modo config, só existe ali.
2. Conecte o celular nessa rede. O captive portal abre a página sozinho (se não
   abrir, vá em `http://192.168.4.1`).
3. Toque na sua rede na lista (cadeado = protegida; as barras mostram a
   intensidade do sinal). **Rede oculta?** Digite o nome dela no campo manual.
   Aí é só pôr a senha e **SALVAR** — o botão de buscar de novo refaz o scan na
   hora. O campo da **URL do server** fica nessa mesma página.
4. O aparelho reinicia e conecta. A partir daqui é só usar.

<p align="center">
  página de configuração com o scan de redes
  &nbsp;&nbsp;
  confirmação de rede salva
</p>

A senha da sua rede fica **cifrada na NVS** com chave derivada do MAC em eFuse
do próprio chip. Pra apagar: **Config → Conexões → WiFi/Servidor → esquecer**.

---
## 🐾 Pareando o Claw'd &amp; o dashboard

Com o aparelho online e o server com uma `ANTHROPIC_API_KEY`:

1. No aparelho, vá em **Config → Conexões → QR do aparelho**. A tela mostra um QR
   montado a partir da URL do server e da chave do próprio device.
2. Escaneie com a câmera do celular — o **dashboard abre já logado** (a chave
   viaja no fragmento da URL). Instale como PWA se quiser ("EspNokia Dash").
3. No dashboard, defina a **persona**, o **motor de STT**, o **limite de
   resposta**, leia a **memória** / **conversas** recentes do pet, ou coloque
   suas chaves.
4. Abra o **Claw'd** no aparelho, **segure o botão e fale**, solte — o pet
   escuta, pensa (a ✶ pulsa) e lê a resposta do Claude página por página.

---
## 🚑 Problemas comuns

| Sintoma | Causa provável / solução |
|---|---|
| `pio run -t upload` não acha a porta | Linux: entre no grupo `dialout` (`sudo usermod -aG dialout $USER`, relogue). Confira o driver USB-serial da placa (CP2102/CH340) |
| Display liga mas não mostra nada | Contraste/conexões: confira CLK/DIN/DC/CE/RST contra a [pinagem](#-pinagem); o 5110 é sensível a jumper frouxo |
| Um app pede "Conecte o WiFi" | O aparelho não tem rede configurada — faça o [provisionamento](#-conectando-no-wifi) |
| Um app mostra "SEM RESPOSTA" | O firmware não obteve um 200 do server: confira a URL (IP certo? porta certa? sem barra no fim?), se o server está de pé (`curl .../health`) e se a chave do device é aceita (chave fraca/desconhecida = 401) |
| O Claw'd nunca responde | O server está sem `ANTHROPIC_API_KEY`, ou o mic não está ligado (SCK 33 / WS 32 / SD 35, `L/R` no GND) |
| Relógio sem hora / sem alarme | DS3231 ausente ou SDA/SCL trocados; sem RTC o relógio funciona, mas alarme não |
| Toques sem som ou som contínuo | Buzzer ativo no lugar do passivo, ou polaridade invertida |

---

<p align="center">
  Montou? → <a href="../README.pt-br.md"><b>📟 Volta pro tour do projeto</b></a>
</p>

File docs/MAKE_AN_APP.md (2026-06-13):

<h3 align="center">
  <a href="../README.md">📟 Back to the project</a>&nbsp;&nbsp;·&nbsp;&nbsp;🧩 Make your own app
</h3>

<p align="center">
  🇬🇧 English&nbsp;&nbsp;·&nbsp;&nbsp;<a href="MAKE_AN_APP.pt-br.md">🇧🇷 Português</a>
</p>

# Make your own app

> This is a **pointer, not a rulebook** — a suggested path for adding your own
> screen to NokiaOS. The shell is small on purpose; once you've seen one app,
> you can bend the rest to taste.

NokiaOS is an **app shell**. Each app is a plain struct of callbacks the shell
calls at the right moments — there's no inheritance, no framework. Adding one is
three small steps: **write the app, give it a name, register it.**

## 1. The contract

Every app fills in [`firmware/lib/nokiacore/app.h`](../firmware/lib/nokiacore/app.h).
Any callback you don't need can be `nullptr`:

```cpp
struct App {
  uint8_t name_id;                         // its name in the launcher (an i18n StrId)
  void (*on_enter)();                      // opened — set up state
  void (*on_tick)(uint32_t now_ms);        // called every loop — animate, poll
  bool (*on_input)(Button b, BtnEvent e);  // a key event — return true if you consumed it
  void (*on_exit)();                       // closed — tear down
  void (*on_render)(void* gfx);            // draw a frame (cast to U8G2*)
  const unsigned char* icon;               // 28×24 XBM for the menu (or nullptr)
  const unsigned char* const* anim;        // 28×24 frames ending in nullptr (or nullptr)
};
```

`on_render` takes a `void*` so the core stays hardware-agnostic; the glue passes
a `U8G2*`. Cast it once and draw.

## 2. A minimal app

Create `firmware/src/apps/app_hello.h`:

```cpp
#pragma once
#include "app.h"
extern const App app_hello;
```

…and `firmware/src/apps/app_hello.cpp`:

```cpp
#include "app_hello.h"
#include <U8g2lib.h>
#include "i18n.h"
#include "ui/fonts3310.h"
#include "ui/nokia_ui.h"

static uint8_t taps_ = 0;

static void on_enter() { taps_ = 0; }

static bool on_input(Button b, BtnEvent e) {
  if (b == Button::OK && e == BtnEvent::PRESS) { taps_++; return true; }
  return false;   // let the shell handle C (back), UP/DOWN, etc.
}

static void render(void* gfx) {
  U8G2& g = *(U8G2*)gfx;
  g.setFont(u8g2_font_3310_small);
  nokia_ui::text_bold_center(g, 8, tr(STR_APP_HELLO));
  char buf[16];
  snprintf(buf, sizeof(buf), "taps: %u", taps_);
  g.drawUTF8(2, 28, buf);
  nokia_ui::softkey(g, tr(STR_BACK));
}

const App app_hello = {STR_APP_HELLO, on_enter, nullptr, on_input,
                       nullptr, render, nullptr, nullptr};
```

Helpers worth knowing (see [`nokia_ui.h`](../firmware/src/ui/nokia_ui.h)):
`text_bold_center`, `text_bold`, `softkey`. For accented text use `drawUTF8`
(`drawStr` stops at ASCII 127). The body font is `u8g2_font_3310_small`.

## 3. Name it (i18n)

The launcher shows `name_id`, a string id from the i18n table in
[`firmware/lib/i18n`](../firmware/lib/i18n). Add `STR_APP_HELLO` (and any other
strings the app shows) there, with a translation per language — `tr(id)` returns
the right one at runtime. Keeping user-facing text in i18n is what keeps the
device in 9 languages for free.

## 4. Register it

In [`firmware/src/main.cpp`](../firmware/src/main.cpp), include the header and
drop the app into the launcher list:

```cpp
#include "apps/app_hello.h"

static const App* kApps[] = {&app_clock,   &app_claude, &app_esportes,
                             &app_weather, &app_tones,  &app_hello,
                             &app_settings};
```

That's it — build, flash, and your app is in the menu.

## 5. Optional: an icon &amp; selection animation

Menu icons are **28×24 bitmaps written as text** in
[`firmware/assets/assets.txt`](../firmware/assets/assets.txt) (a tiny grid DSL —
`#` is a lit pixel) and compiled to XBM by the tool in [`tools/`](../tools):

```bash
python3 tools/grid2xbm.py firmware/assets/assets.txt --header firmware/src/ui/assets.h
```

Then point `icon` at `icon_hello_bits`, and optionally give `anim` an array of
frames (ending in `nullptr`) the menu plays once when the app is selected.

## 6. Optional: talk to the server

If your app needs data from the companion server, reuse the connection the rest
of the device already shares — [`firmware/src/net/conn.h`](../firmware/src/net/conn.h)
gives you `conn::server_url()` and `conn::device_key()`. Add your route on the
[FastAPI side](../server/app/main.py), guard it with the same `X-Device-Key`
dependency as the others, and return **lean JSON** (the ESP32 parses with a small
ArduinoJson buffer — keep fields short).

## 7. Test it on the PC

Pure logic (parsing, formatting, state) can be tested with **no board**:

```bash
cd firmware
pio test -e native
```

Keep the testable logic in `lib/` (portable, no Arduino headers) and the drawing
in `apps/` — that split is what lets the PC run the same code the ESP32 does.

---

<p align="center">
  Built something? → <a href="../README.md"><b>📟 Back to the project</b></a>
</p>

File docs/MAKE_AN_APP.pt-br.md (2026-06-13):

<h3 align="center">
  <a href="../README.pt-br.md">📟 Voltar pro projeto</a>&nbsp;&nbsp;·&nbsp;&nbsp;🧩 Crie seu próprio app
</h3>

<p align="center">
  <a href="MAKE_AN_APP.md">🇬🇧 English</a>&nbsp;&nbsp;·&nbsp;&nbsp;🇧🇷 Português
</p>

# Crie seu próprio app

> Isto é um **direcionamento, não uma regra** — um caminho sugerido pra você
> adicionar a sua própria tela ao NokiaOS. O shell é pequeno de propósito; depois
> de ver um app, dá pra moldar o resto do seu jeito.

O NokiaOS é um **app shell**. Cada app é uma struct simples de callbacks que o
shell chama nos momentos certos — sem herança, sem framework. Adicionar um são
três passos pequenos: **escrever o app, dar um nome, registrar.**

## 1. O contrato

Todo app preenche o [`firmware/lib/nokiacore/app.h`](../firmware/lib/nokiacore/app.h).
Qualquer callback que você não precisar pode ser `nullptr`:

```cpp
struct App {
  uint8_t name_id;                         // o nome no launcher (um StrId do i18n)
  void (*on_enter)();                      // abriu — prepare o estado
  void (*on_tick)(uint32_t now_ms);        // todo loop — animar, consultar
  bool (*on_input)(Button b, BtnEvent e);  // tecla — retorne true se consumiu
  void (*on_exit)();                       // fechou — limpe
  void (*on_render)(void* gfx);            // desenhe um frame (cast pra U8G2*)
  const unsigned char* icon;               // XBM 28×24 pro menu (ou nullptr)
  const unsigned char* const* anim;        // frames 28×24 terminando em nullptr (ou nullptr)
};
```

`on_render` recebe um `void*` pra manter o core agnóstico de hardware; o glue
passa um `U8G2*`. Faça o cast uma vez e desenhe.

## 2. Um app mínimo

Crie `firmware/src/apps/app_hello.h`:

```cpp
#pragma once
#include "app.h"
extern const App app_hello;
```

…e `firmware/src/apps/app_hello.cpp`:

```cpp
#include "app_hello.h"
#include <U8g2lib.h>
#include "i18n.h"
#include "ui/fonts3310.h"
#include "ui/nokia_ui.h"

static uint8_t taps_ = 0;

static void on_enter() { taps_ = 0; }

static bool on_input(Button b, BtnEvent e) {
  if (b == Button::OK && e == BtnEvent::PRESS) { taps_++; return true; }
  return false;   // deixa o shell tratar C (voltar), UP/DOWN, etc.
}

static void render(void* gfx) {
  U8G2& g = *(U8G2*)gfx;
  g.setFont(u8g2_font_3310_small);
  nokia_ui::text_bold_center(g, 8, tr(STR_APP_HELLO));
  char buf[16];
  snprintf(buf, sizeof(buf), "taps: %u", taps_);
  g.drawUTF8(2, 28, buf);
  nokia_ui::softkey(g, tr(STR_BACK));
}

const App app_hello = {STR_APP_HELLO, on_enter, nullptr, on_input,
                       nullptr, render, nullptr, nullptr};
```

Helpers que valem conhecer (veja [`nokia_ui.h`](../firmware/src/ui/nokia_ui.h)):
`text_bold_center`, `text_bold`, `softkey`. Pra texto com acento use `drawUTF8`
(`drawStr` para no ASCII 127). A fonte do corpo é `u8g2_font_3310_small`.

## 3. Dê um nome (i18n)

O launcher mostra o `name_id`, um id de string da tabela de i18n em
[`firmware/lib/i18n`](../firmware/lib/i18n). Adicione `STR_APP_HELLO` (e qualquer
outra string que o app exiba) lá, com uma tradução por idioma — `tr(id)` devolve
a certa em runtime. Manter o texto do usuário no i18n é o que mantém o aparelho
em 9 idiomas de graça.

## 4. Registre

No [`firmware/src/main.cpp`](../firmware/src/main.cpp), inclua o header e coloque
o app na lista do launcher:

```cpp
#include "apps/app_hello.h"

static const App* kApps[] = {&app_clock,   &app_claude, &app_esportes,
                             &app_weather, &app_tones,  &app_hello,
                             &app_settings};
```

Pronto — compile, grave, e o seu app está no menu.

## 5. Opcional: um ícone &amp; animação de seleção

Os ícones do menu são **bitmaps 28×24 escritos como texto** em
[`firmware/assets/assets.txt`](../firmware/assets/assets.txt) (um pequeno DSL de
grade — `#` é um pixel aceso) e compilados pra XBM pela ferramenta em
[`tools/`](../tools):

```bash
python3 tools/grid2xbm.py firmware/assets/assets.txt --header firmware/src/ui/assets.h
```

Depois aponte o `icon` pra `icon_hello_bits` e, se quiser, dê ao `anim` um array
de frames (terminando em `nullptr`) que o menu toca uma vez quando o app é
selecionado.

## 6. Opcional: falar com o server

Se o seu app precisa de dados do server companion, reaproveite a conexão que o
resto do aparelho já compartilha — [`firmware/src/net/conn.h`](../firmware/src/net/conn.h)
te dá `conn::server_url()` e `conn::device_key()`. Adicione a sua rota no
[lado FastAPI](../server/app/main.py), proteja com a mesma dependência
`X-Device-Key` das outras, e responda **JSON enxuto** (o ESP32 parseia com um
buffer pequeno do ArduinoJson — mantenha os campos curtos).

## 7. Teste no PC

Lógica pura (parsing, formatação, estado) dá pra testar **sem placa**:

```bash
cd firmware
pio test -e native
```

Mantenha a lógica testável em `lib/` (portável, sem headers do Arduino) e o
desenho em `apps/` — essa divisão é o que deixa o PC rodar o mesmo código que o
ESP32 roda.

---

<p align="center">
  Fez algo? → <a href="../README.pt-br.md"><b>📟 Voltar pro projeto</b></a>
</p>

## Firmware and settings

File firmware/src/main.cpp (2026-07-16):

#include <Arduino.h>
#include <U8g2lib.h>
#include "alarm.h"
#include "copa_watch.h"
#include "pins.h"
#include "shell.h"
#include "sound.h"
#include "drivers/backlight.h"
#include "drivers/buzzer.h"
#include "drivers/buttons.h"
#include "drivers/mic.h"
#include "drivers/rtc.h"
#include "net/conn.h"
#include "net/wifi.h"
#include "net/ntp.h"
#include "ui/boot_anim.h"
#include "ui/goal_fx.h"
#include "ui/menu_view.h"
#include "apps/app_standby.h"
#include "apps/app_clock.h"
#include "apps/app_claude.h"
#include "apps/app_esportes.h"
#include "apps/app_weather.h"
#include "apps/app_tones.h"
#include "apps/app_settings.h"
#include "apps/app_jogos.h"

static U8G2_PCD8544_84X48_F_4W_HW_SPI u8g2(U8G2_R0, PIN_LCD_CE, PIN_LCD_DC, PIN_LCD_RST);
static Shell shell;
static const App* kApps[] = {&app_clock,  &app_claude,   &app_esportes,
                             &app_weather, &app_tones, &app_jogos,
                             &app_settings};

void setup() {
  Serial.begin(115200);
  settings_load_lang();  // idioma salvo na NVS, antes do primeiro render
  backlight::init();  // PWM + nivel salvo na NVS
  u8g2.begin();
  u8g2.setContrast(140);
  buzzer::init();
  sound::init();  // volume + toque padrao salvos na NVS
  buttons::init();
  if (rtc::init()) {
    rtc::DateTime dt;
    rtc::now(dt);
    Serial.printf("[rtc] %04u-%02u-%02u %02u:%02u:%02u  %.2fC\n", dt.year,
                  dt.month, dt.day, dt.hour, dt.min, dt.sec, rtc::temperature());
  } else {
    Serial.println("[rtc] DS3231 ausente — relogio de videocassete");
  }
  conn::init();                       // chave do device + endereco do server (NVS)
  alarme::init();                     // recarrega aviso de jogo persistido
  copa_watch::init();                 // recarrega vigia de gols persistido
  wifi::init();                      // nao-bloqueante; conecta enquanto a animacao roda
  boot_anim_play(u8g2);              // logo NOKIA + maos + startup chime (segura ate o fim)
  shell.init(&app_standby, kApps, sizeof(kApps) / sizeof(kApps[0]));
}

void loop() {
  uint32_t now = millis();

  Button b; BtnEvent e;
  if (buttons::poll(now, b, e)) {
    if (!goal_fx::input(b, e)) {                    // overlays engolem teclas
      if (!alarme::input(b, e)) shell.input(b, e);
    }
    // bip de tecla so DEPOIS do input: a tecla que liga o mic (e qualquer
    // outra durante a gravacao) fica muda. Bipar antes segurava um tom de
    // 900 Hz ligado durante todo o handshake TLS do begin() — o tick que o
    // desligaria nao roda enquanto o input bloqueia.
    // (o auto-repeat de segurar UP/DOWN tambem fica mudo: 9 bips/s cansa)
    if (e == EV_PRESS && !mic::running() && !buttons::repeating())
      sound::play(sound::SND_KEY);
  }
  shell.tick(now);
  buzzer::tick(now);
  wifi::tick(now);
  ntp::tick(now);
  alarme::tick(now);
  copa_watch::tick(now);
  goal_fx::tick(now);

  static uint32_t last_render = 0;
  if (now - last_render >= 50) {                // ~20 fps
    last_render = now;
    u8g2.clearBuffer();
    if (shell.screen() == Shell::LAUNCHER) menu_view_draw(u8g2, shell);
    else if (shell.active() && shell.active()->on_render)
      shell.active()->on_render(&u8g2);
    if (alarme::active()) alarme::render(&u8g2);  // overlay por cima de tudo
    if (goal_fx::active()) goal_fx::render(&u8g2);  // gol por cima ate do alarme
    u8g2.sendBuffer();
  }
  delay(2);
}

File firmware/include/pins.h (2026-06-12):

#pragma once
// espnokia-phone — pinagem v5 (única fonte da verdade; tabela em docs/INSTALL.md)
#define PIN_LCD_CLK  18  // VSPI SCK
#define PIN_LCD_DIN  23  // VSPI MOSI
#define PIN_LCD_DC   17
#define PIN_LCD_CE    5
#define PIN_LCD_RST  16
#define PIN_LCD_BL    4  // backlight PWM
#define PIN_BTN_UP   13
#define PIN_BTN_DOWN 14
#define PIN_BTN_OK   27
#define PIN_BTN_C    26
#define PIN_BUZZER   25
#define PIN_I2C_SDA  21  // DS3231 (RTC)
#define PIN_I2C_SCL  22
#define PIN_VBAT     36  // F4 (divisor de tensão)
// F3 (mic I2S) — INMP441, L/R no GND (canal esquerdo)
#define PIN_MIC_SCK  33
#define PIN_MIC_WS   32
#define PIN_MIC_SD   35

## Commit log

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2026-06-11 fix(firmware): rtttl rejeita input malformado com seguranca
    - Valida def_dur_ e bpm_ != 0 após parse do header
    - Previne overflow de semi na tabela kOct4 (máx 11)
    - Rejeita oitavas fora do intervalo 4-7 (shift inválido)
    - Novo teste: malformed_input_fails_safely (5 casos)
    [main.cpp]
2026-06-11 feat(firmware): driver buzzer LEDC nao-bloqueante + nokia tune no boot
    Adiciona namespace buzzer com implementação não-bloqueante:
    - init(): setup do LEDC no pino PIN_BUZZER (canal 0, 2kHz base)
    - play(): toca RTTTL sem bloquear main loop
    - beep(): bip único para feedback de tecla
    - tick(): chama-se a cada iteração do loop() para avanço de notas
    - stop()/busy(): controle de estado
    Nokia tune toca na sequência de setup(), enquanto display smoke test fica intacto.
    [buzzer.cpp, main.cpp]
2026-06-11 fix(firmware): buzzer respeita gap entre notas e rollover de millis
    - Adiciona tone_end_ (90% — fim do som) separado de note_end_ (100% — busca próxima)
    - Gap de 10% entre notas agora é preservado (tone_for não é sobrescrito pelo caller)
    - Implementa reached() com comparação segura para rollover de millis() aos 49.7 dias
    - play() agora chama stop() primeiro para interromper beep ativo
    [buzzer.cpp]
2026-06-11 docs: corrige driver do buzzer no plano F1 (gap entre notas e rollover)
2026-06-11 feat(firmware): debounce testado + driver de 4 botoes com keypad beep
    TDD: btnlogic.h/cpp com BtnState + btn_step(), passa 3 testes de estabilidade
    e rejeição de bounce. buttons.h/cpp varrem os 4 pinos (ativo-baixo) a cada poll(),
    retorna primeiro evento do ciclo. main.cpp integra com Serial (115200), buttons::init()
    no setup(), loop examina poll() e beep(1250, 40) em EV_PRESS, imprime nome.
    Compile: esp32dev OK (291KB flash, 22KB RAM). Tests: 8 passed (3 btnlogic + 5 rtttl).
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2026-06-11 feat(buzzer): tune_busy e beep de tecla sem interromper tune
    [buzzer.cpp, main.cpp]
2026-06-11 feat(boot): pixel art e chime fieis ao boot do Nokia 1100
    - maos recuperadas da tela real do 1100 (mao adulta 49x31 com dithering
    original + mao de bebe 33x18), logo NOKIA bold 72x8 embaixo
    - chime exato: 5 notas finais do Nokia tune (B-A-C#-E-A em La maior),
    nota final pontuada, A5 a 880 Hz como no piezo original
2026-06-11 feat(tones): toques originais de fabrica da Nokia com lista rolavel
    9 transcricoes RTTTL da era 3310/1100 (Nokia tune, Ring ring, City Bird,
    Groovy Blue, Entertainer, Toreador, Minuet, Circles, Auld Lang Syne);
    janela de 3 itens com scrollbar igual ao menu
2026-06-11 feat(ui): identidade ESPNOKIA — emblema eN e wordmark em pixel art no standby
2026-06-11 feat(settings): app de configuracoes com backlight ajustavel e Sobre em 3 paginas
2026-06-11 fix(buzzer): keypad beep fiel ao 3310 — 900 Hz / 90ms medidos de aparelho real
    [main.cpp]
2026-06-11 fix(standby): relogio em posicao fixa — colon piscando nao desloca nem corta os digitos
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2026-06-11 feat(settings): secao Data e hora — toggle de sincronizacao (NVS) + acerto manual estilo 3310
    UP/DOWN ajusta o campo invertido, OK avanca, C volta; dia da semana
    derivado da data (Sakamoto). days_in_month/date_weekday na lib clockfmt
    com testes nativos (bissexto secular incluso).
2026-06-11 feat(weather): app Clima com a temperatura de bordo do DS3231
    Icone termometro+sol 28x24; digitos grandes com simbolo de grau
    desenhado (a fonte nao tem). Previsao via API fica pra fase do WiFi. fw 0.3.2
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2026-06-11 feat(server): servico copa com proximos, brasil e janela de jogo ao vivo
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2026-06-11 chore: versao 0.4.0 — F2 completa (server copa + wifi + ntp + app copa)
2026-06-11 fix(ui): texto das listas 1px mais baixo, centrado na barra de selecao
2026-06-11 feat(wifi): modo config via AP — portal web salva a rede cifrada na NVS
2026-06-11 feat(config): tela Wifi real — rede e IP, esquecer ou trocar a rede
2026-06-11 feat(ui): wifi no HUD so com rede conectada + tela padrao de sem conexao
2026-06-11 feat(wifi): AP do modo config com senha WPA2 de 8 digitos sorteada no boot
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2026-06-11 feat(alarm): avisos generalizados — titulo por string, trigger e timer
    O alarme de jogo vira a infra de notificacao do aparelho: o overlay ganha
    titulo configuravel (Alarme/TEMPO!/JOGO AGORA), trigger() dispara aviso
    imediato pra qualquer app e um timer regressivo conta minutos por millis
    (volatil de proposito: reboot cancela, como nos fornos).
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2026-06-12 fix(copa): tira o bip de erro e troca REDE OCUPADA por SEM RESPOSTA
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2026-06-12 fix(som): escada de volume do piezo ordenada pela loudness real
    [buzzer.cpp]
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2026-06-12 firmware: silencia bip de tecla durante gravacao de voz
    o bip da tecla OK tocava no instante em que o mic comecava a capturar
    e vazava pra gravacao; teclas apertadas durante a escuta tambem
    bipariam. buzzer::stop() antes do mic::start() e tecla muda enquanto
    mic::running().
    [app_claude.cpp, main.cpp]
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2026-06-13 server: resposta cortada no mesmo teto da fala ao vivo e do registro (coesao de texto, sem buga retorno)
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2026-06-13 docs: README vira vitrine por categoria (arquitetura pro fim), boot das maos em gif, logos Claude/Copa discretos, fotos de cabeca pra baixo corrigidas e INSTALL dividido em setores
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2026-07-04 hardware: STLs finais da case v1 — frente e capa
    Frente: logo ESPNOKIA em relevo leve (tela<->navegacao), botao power
    FICTICIO (simbolo em relevo, sem furo — estilo teclado) e fenda 4,2x2,6
    na lateral direita p/ a mini chave liga/desliga (power da v1).
    Capa: logotipo completo (simbolo eN + letras) gravado 0,4mm no domo.
    .gitignore: hardware entra no repo apenas com esses 2 STLs (fontes
    OpenSCAD e artefatos de trabalho ficam locais).
    [case-capa.stl]
2026-07-05 hardware: STLs v1 corrigidos — domo da capa 2,0mm real (quebrava na torção), anel do mic 2,8, + rodada 04/jul (junta, chave, USB, margem tela)
2026-07-05 hardware: versiona switch-teste (placa de calibração, cotas = frente) e sim-tela-modulo (mockup 5110 p/ FreeCAD)
    [sim-tela-modulo.stl, switch-teste.stl]
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2026-07-05 hardware: USB da capa = só um furo passante 11x5 centrado na boca — sem nicho, sem reforço (revertidos)
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2026-07-06 hardware: berço recalibrado p/ switch corpo 3,81 (trava quebrava por 0,75 de interferência) + discos extensores do atuador (ponta 0,9 além do relevo, relevo intacto)
    [extensor-atuador.stl, switch-teste.stl]
2026-07-06 hardware: botão sem cola — pele 0,2 + folga 0,10 + relevo nav 0,4 → ponta 0,94 fora da face (0,54 acima do botão), extensor vira opcional
    [switch-teste.stl]
2026-07-06 hardware: switch-teste com botão OK real (relevo+símbolo) e relevo pra cima — teste de clique fiel
    [switch-teste.stl]
2026-07-06 hardware: botões de ação em CONTORNO (aresta 0,8×0,4, miolo na face) — clique leve, atuador domina; símbolos 0,7 abaixo da ponta
    [switch-teste.stl]
2026-07-06 hardware: botões de ação +20% (NAV_ESCALA 1,30) — contornos maiores, furos/berços parados, vãos conferidos
    [switch-teste.stl]
2026-07-06 hardware: botões 1,40 + furo re-centrado no incentro escalado + aresta 0,7 — folga furo↔contorno 0,8+ nas setas
    [switch-teste.stl]
2026-07-06 hardware: botões de ação na escala FINAL 1,19 (−15% sobre 1,40)
    [switch-teste.stl]
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2026-07-15 firmware: extrai timeutil.h (minuto/reached) das 5 cópias duplicadas
    minuto() estava copiada byte-a-byte em alarm.cpp, copa_watch.cpp e
    jogo_aviso.cpp; reached() (comparação de millis() imune a rollover)
    duplicada em alarm.cpp/buzzer.cpp e reimplementada inline em
    copa_watch.cpp. Move as duas pra firmware/lib/timeutil/timeutil.h
    (header-only) e ajusta os 5 call sites, sem mudar a aritmética.
    Bônus (C-baixa): provision.cpp:246 era a única comparação de millis()
    sem proteção contra rollover — troca por timeutil::reached().
    Adiciona teste nativo test_timeutil cobrindo rollover de reached() e
    a fórmula de minuto().
    [buzzer.cpp, main.cpp]
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2026-07-15 firmware: i18n nos nomes do nivel de backlight (config > visor)
    kNames hardcoded em PT ("Desligada"/"Media"/"Alta") nunca passava por
    tr(), diferente do resto da tela de Configuracoes; "Media" tambem
    estava sem acento. Segue o padrao do volume: app_settings resolve os
    rotulos via tr() na hora de desenhar (STR_DISP_OFF/MED/HIGH), sem
    depender de i18n na camada de driver.
    [backlight.cpp]
2026-07-15 firmware: corrige truncamento da chave no QR de pareamento
    char link[120] recebia conn::pair_link() = "%s/#k=%s" de url_[96] (ate
    90 chars pelo maxlength do form de provisioning) + key_[40] (ate 39
    chars). Pior caso 90+4+39=133 chars estourava os 119 uteis do buffer;
    snprintf truncava em silencio o fim da string, cortando os ultimos
    digitos da device key. QR "Escaneie p/ logar" ficava com chave
    incompleta e o pareamento falhava sem erro visivel. Buffer agora com
    160 bytes (folga sobre o pior caso). Limiar de versao do QR (78/106)
    nao muda: 133 ainda cabe na capacidade de byte-mode ECC_LOW da
    versao 6 (134).
2026-07-15 firmware: i18n nos cabecalhos de tabela P/J/S (copa/futebol)
    Cabecalhos "P"/"J"/"S" (Pontos/Jogos/Saldo) em 3 pontos de desenho
    (app_copa.cpp classificacao por grupo; app_futebol.cpp grupo e tabela
    unica) eram literais fixos em PT, nunca traduzidos, enquanto o resto
    das telas usa tr(). Novos StrIds STR_TBL_PTS/JOGOS/SALDO com glifos
    curtos (<=3 chars) por idioma para caber nas colunas estreitas
    (~12-16px a 34/50/62 e 40/54/66). Larguras conferidas com a fonte real
    (u8g2_font_3310_small via getStrWidth, medido fora da arvore com o
    decoder do u8g2 vendorizado): a pior combinacao ("Pkt", 12px) ainda
    sobra ~2-4px de vao antes do proximo cabecalho.
2026-07-15 firmware: comenta que os literais da tela Sobre sao intencionais
    "Nokia OS fake" (tagline/flavor, como "CLAWD"), "ESP32 + 5110" e "CPU
    240MHz" (nomes de peca/specs de hardware) ficam fixos em qualquer
    idioma de proposito - nao sao texto de UI escapando do i18n. Adiciona
    comentario pra deixar a decisao explicita e nao parecer descuido.
2026-07-15 firmware: i18n no sufixo " min" do editor de timer
    Sufixo " min" do editor de minutos (app_clock.cpp, V_TIMER) era
    literal fixo, unico rotulo da tela fora do tr(). Trivial de resolver:
    a largura ja era calculada dinamicamente via getStrWidth/getUTF8Width
    para centralizar o campo, entao so trocar o literal por
    tr(STR_MIN_SUFFIX) (drawUTF8 no lugar de drawStr, padrao do resto do
    codebase) nao muda o layout.
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2026-07-15 repo: higiene — protocolo 3MF, peças atuais da case e refs locais
    Remove os 5 STLs obsoletos, adiciona as peças atuais (print/*.3mf,
    sim/*.stl) e o manual LEIA-ME.txt, e atualiza o .gitignore pro protocolo
    3MF. Limpa referências de máquina/fluxo local (~/HistoricoEspnokia,
    'deste PC', histórico do chat) do LEIA-ME e do .gitignore. Ignora
    .superpowers/ (scratch local).
    [case-capa.3mf, espnokia-projeto.3mf, extensor-atuador.stl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]
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2026-07-16 hardware: simplifica p/ 2 peças de impressão (frente multicor + capa)
    O repo agora carrega só o essencial pra imprimir: print/ = frente-multicor.3mf
    (corpo preto + serigrafia branca, 2 cores num só 3mf) + case-capa.3mf; sim/ =
    os 2 STL de conferência de encaixe. Remove do repo (ficam locais) a placa de
    teste do switch, a frente mono (relevo) e o projeto combinado. LEIA-ME e
    .gitignore atualizados.
    [espnokia-projeto.3mf, frente-multicor.3mf, frente-relevo.3mf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]
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2026-07-18 firmware: menu do 2048 (Iniciar/Score/Config), mute geral do sistema no Volume (buzzer+sound), fix do piscar do relogio (colon limpo)
    [buzzer.cpp, main.cpp]
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

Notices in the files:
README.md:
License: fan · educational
